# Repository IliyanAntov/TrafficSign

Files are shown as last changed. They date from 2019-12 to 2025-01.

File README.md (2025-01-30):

 <h1 align="center">Пътен знак с дистанционно управление<br/><br/>
 Adjustable traffic sign</h1>

## [Документация](./Documentation/Thesis/Diplomna_rabota_Iliyan_Antov.pdf)

## [Презентация на проекта](https://docs.google.com/presentation/d/1zqneEv3nR7Rzqj332nx1eZqfj7IUzNgIM3qGUmzLu_I/edit?usp=sharing)
<p align="center" float="left">
  
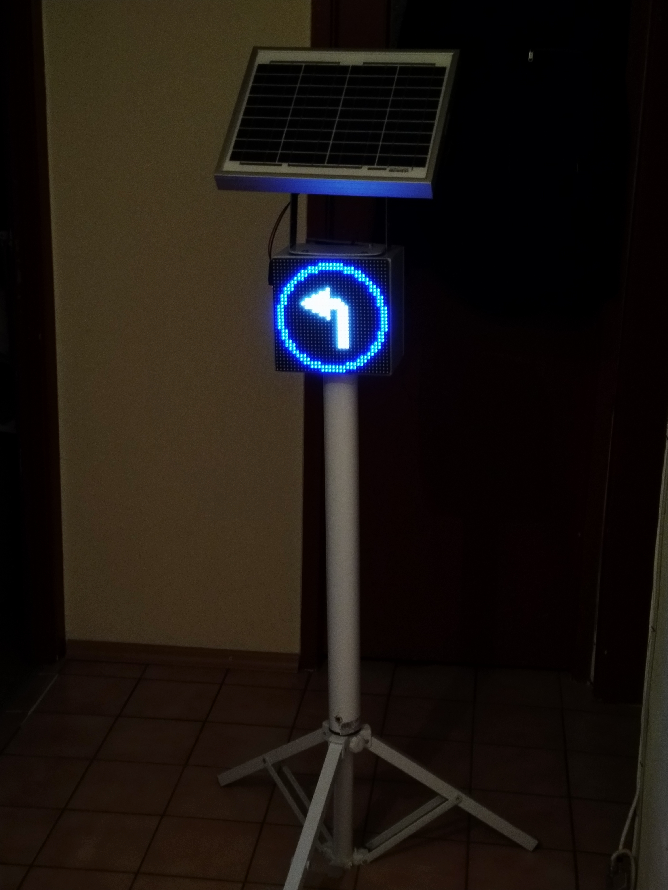
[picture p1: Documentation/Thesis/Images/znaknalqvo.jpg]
  
</p>

*Пътната обстановка се променя постоянно, но знаците, с които обозначаваме правилата, си остават едни и същи. Дипломният проект цели да разреши този проблем - пътният знак с дистанционно управление използва светодиодна матрица, на която могат да се изобразяват произволни предписания според нуждата. Той е свързан към централен сървър с помощта на GPRS връзка, което позволява дистанционното му управление чрез специално разработен управляващ софтуер.*

## Използвани технологии:
* PC application: Python + PyQt5
* Firmware: C/C++ (Arduino)
* MCU platform: AtMega328p + SIM800L
* Schematics/Layout: Altium

## Още снимки:
<p align="center" float="left">
  
  
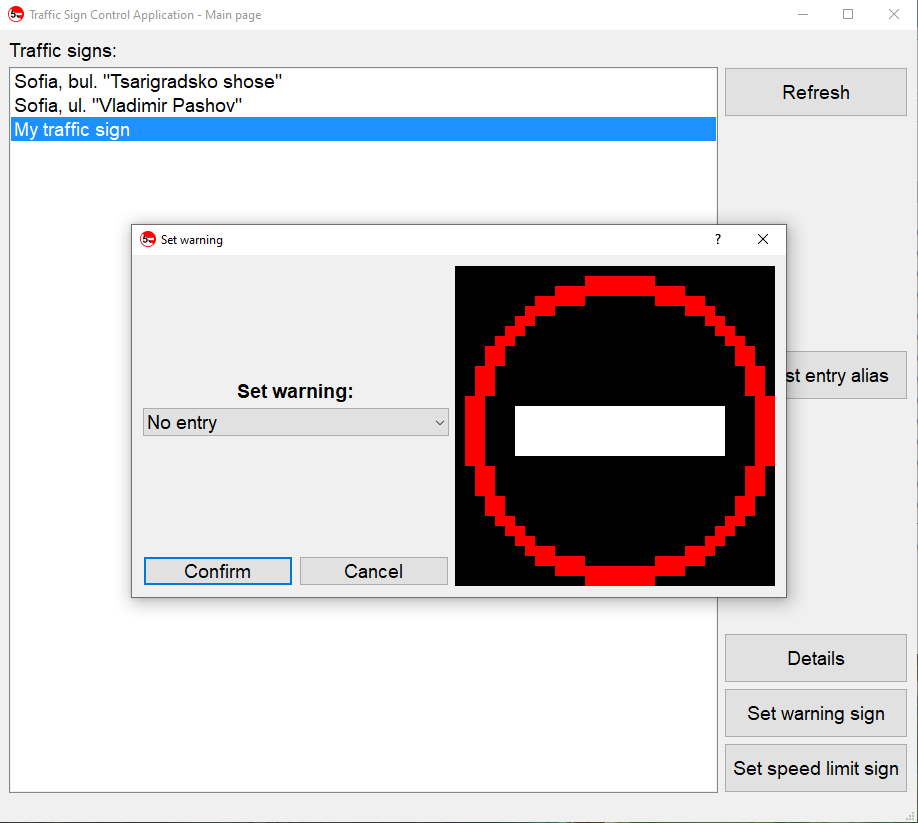
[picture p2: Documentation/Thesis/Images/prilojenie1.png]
  
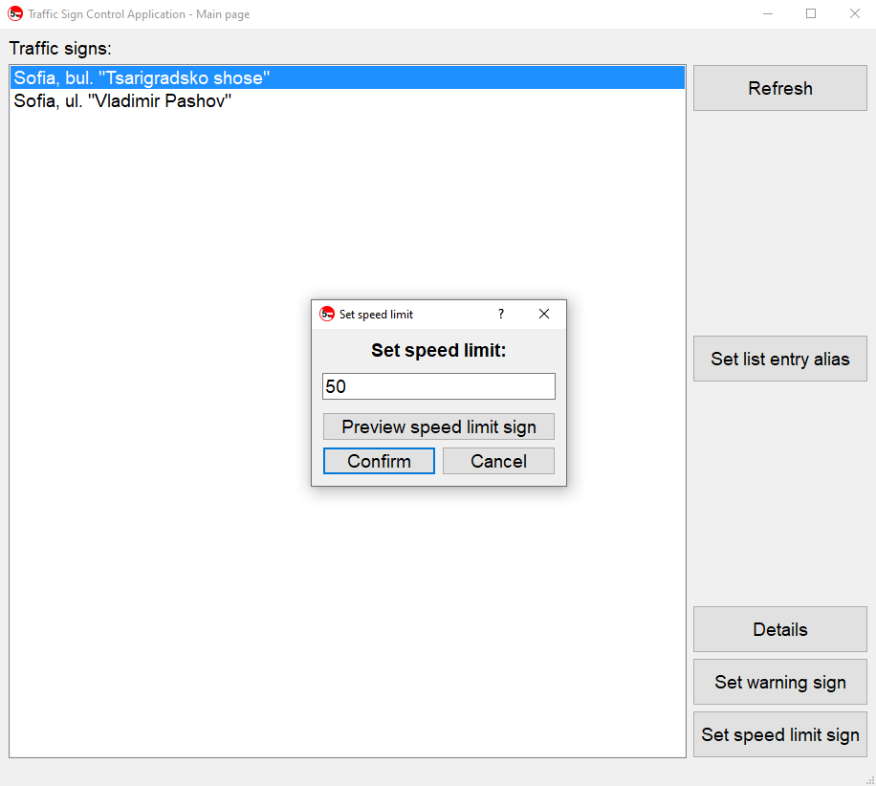
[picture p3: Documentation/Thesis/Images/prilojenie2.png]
  
</p>

## Автор:
Илиян Антов - [Iliyan Antov](https://github.com/IliyanAntov) - [i.antov2@gmail.com](i.antov2@gmail.com)

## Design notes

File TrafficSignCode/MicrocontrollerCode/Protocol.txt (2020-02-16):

Admin app -> Server

"GET ":
    1)  "devices"
        {response}: 
            [message 0]: <Number of available devices>
            [message 1-n]: <Device IMEI>
    2)  "details <IMEI>"
        {response}:
            [message 0]: <Device details string>

"SET <IMEI> ":
    1)  "speed <speed limit>" 
        {response}:
            [message 0]: <Confirmation message>
    2)  "warning <warning sign>"
        {response}:
            [message 0]: <Confirmation message>

Server -> uC

"GET ":
    1)  "dtl" = device details
        {response}:
            [message 0]: <Device details string>

"SET ":
    1)  "spd <speed limit>"
        {response}:
            [message 0]: <Confirmation message>

    2)  "wrn <warning sign code>"
            -"stp" = Stop sign
            -"gnr" = General warning (exclamation mark)
            -"tfl" = Traffic light
            -"nen" = No entry
            -"fon" = Forward only
            -"lon" = Left only
            -"ron" = Right only
        {response}:
            [message 0]: <Confirmation message>

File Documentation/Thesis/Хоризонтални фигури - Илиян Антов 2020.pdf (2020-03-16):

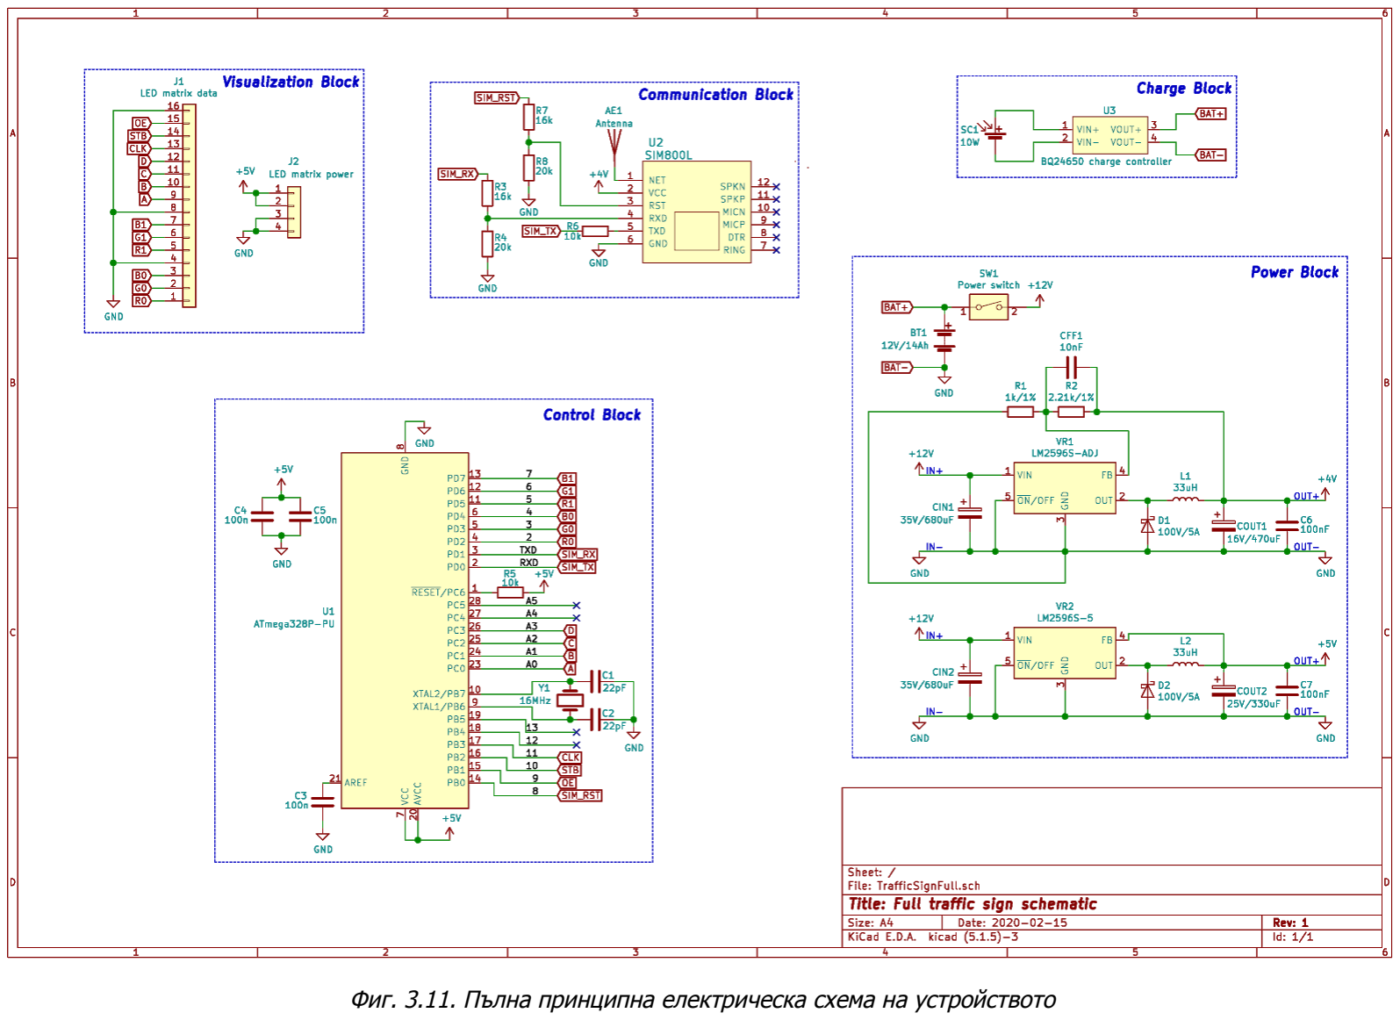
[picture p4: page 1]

Фиг. 3.11. Пълна принципна електрическа схема на устройството

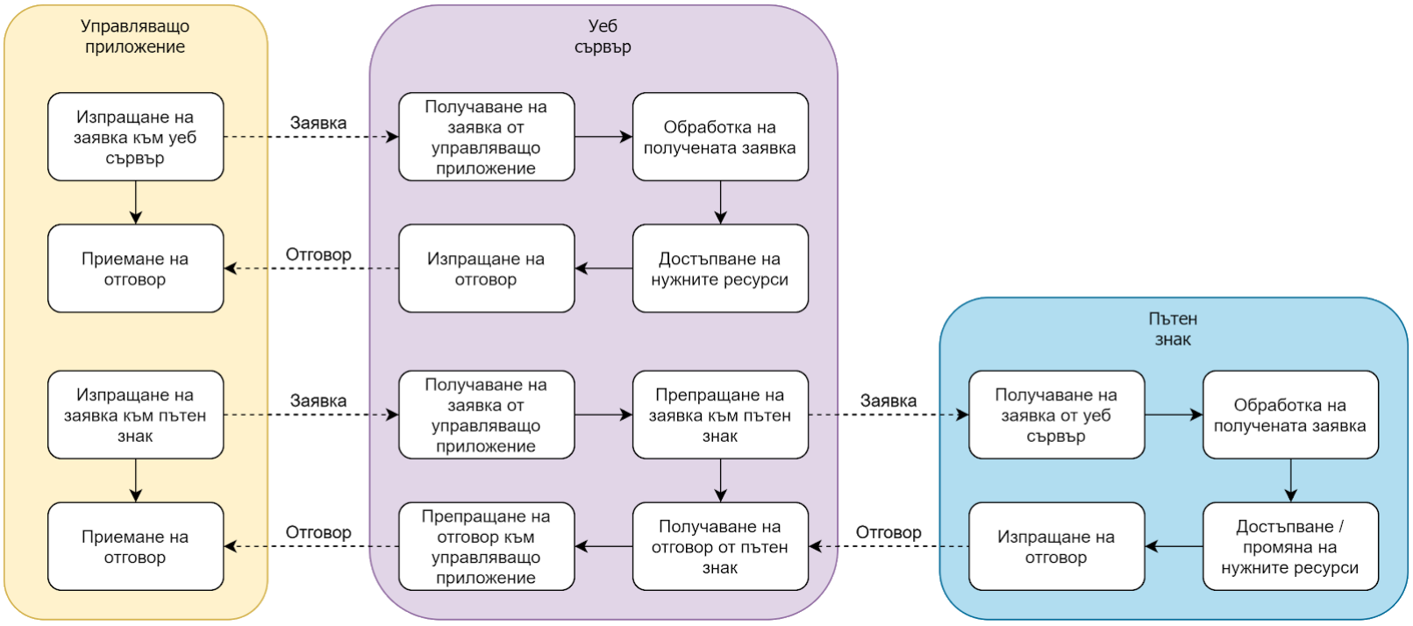
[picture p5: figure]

Фиг. 4.3. Блокова схема на алгоритъм за обмен на информация

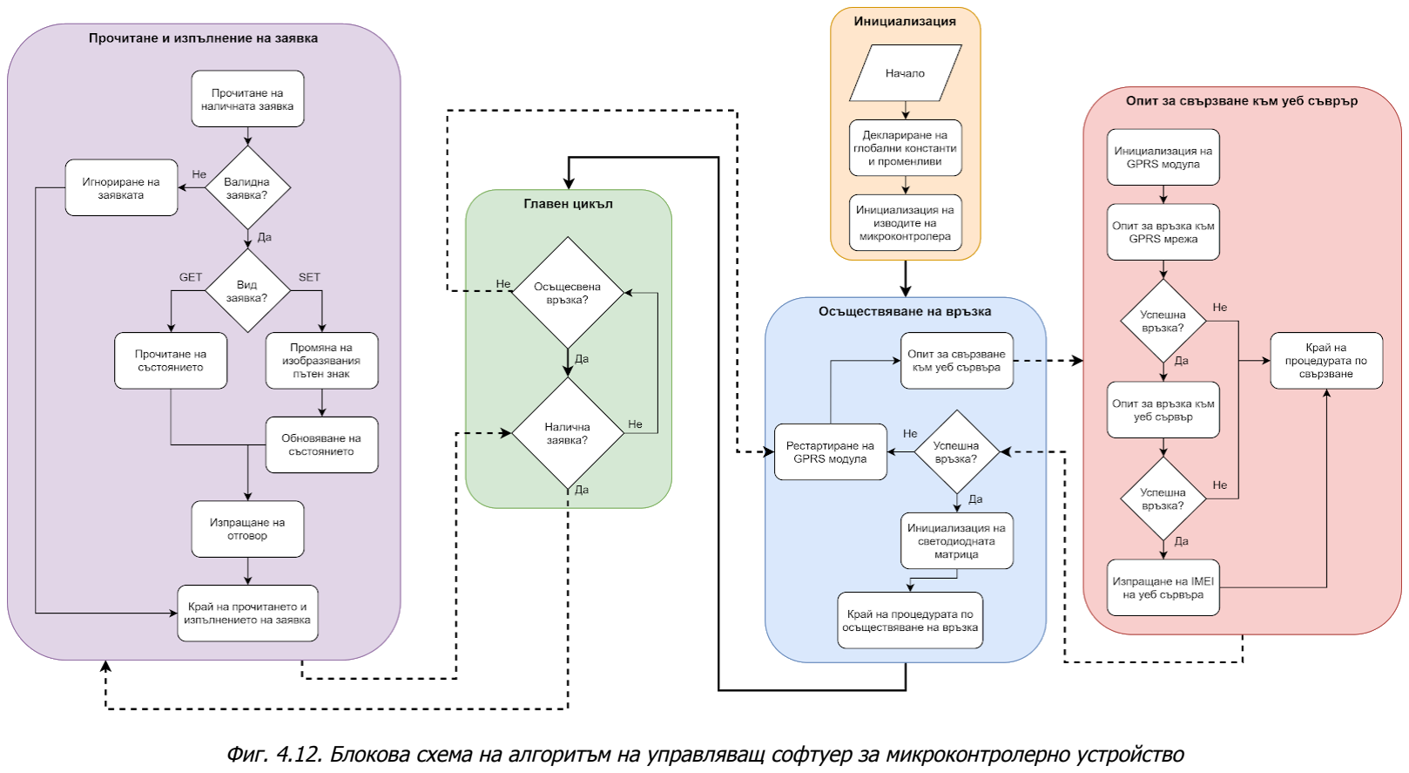
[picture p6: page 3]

Фиг. 4.12. Блокова схема на алгоритъм на управляващ софтуер за микроконтролерно устройство

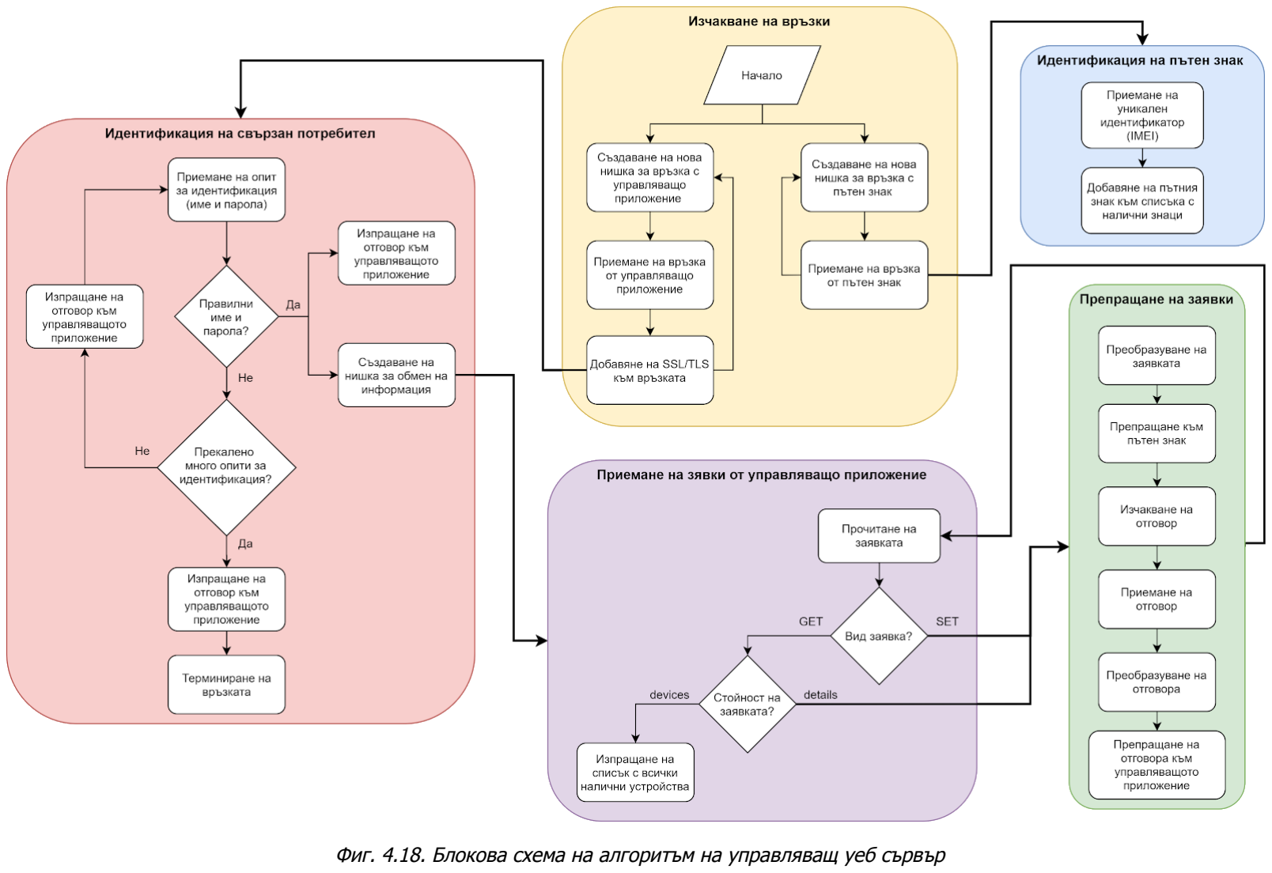
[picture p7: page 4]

Фиг. 4.18. Блокова схема на алгоритъм на управляващ уеб сървър

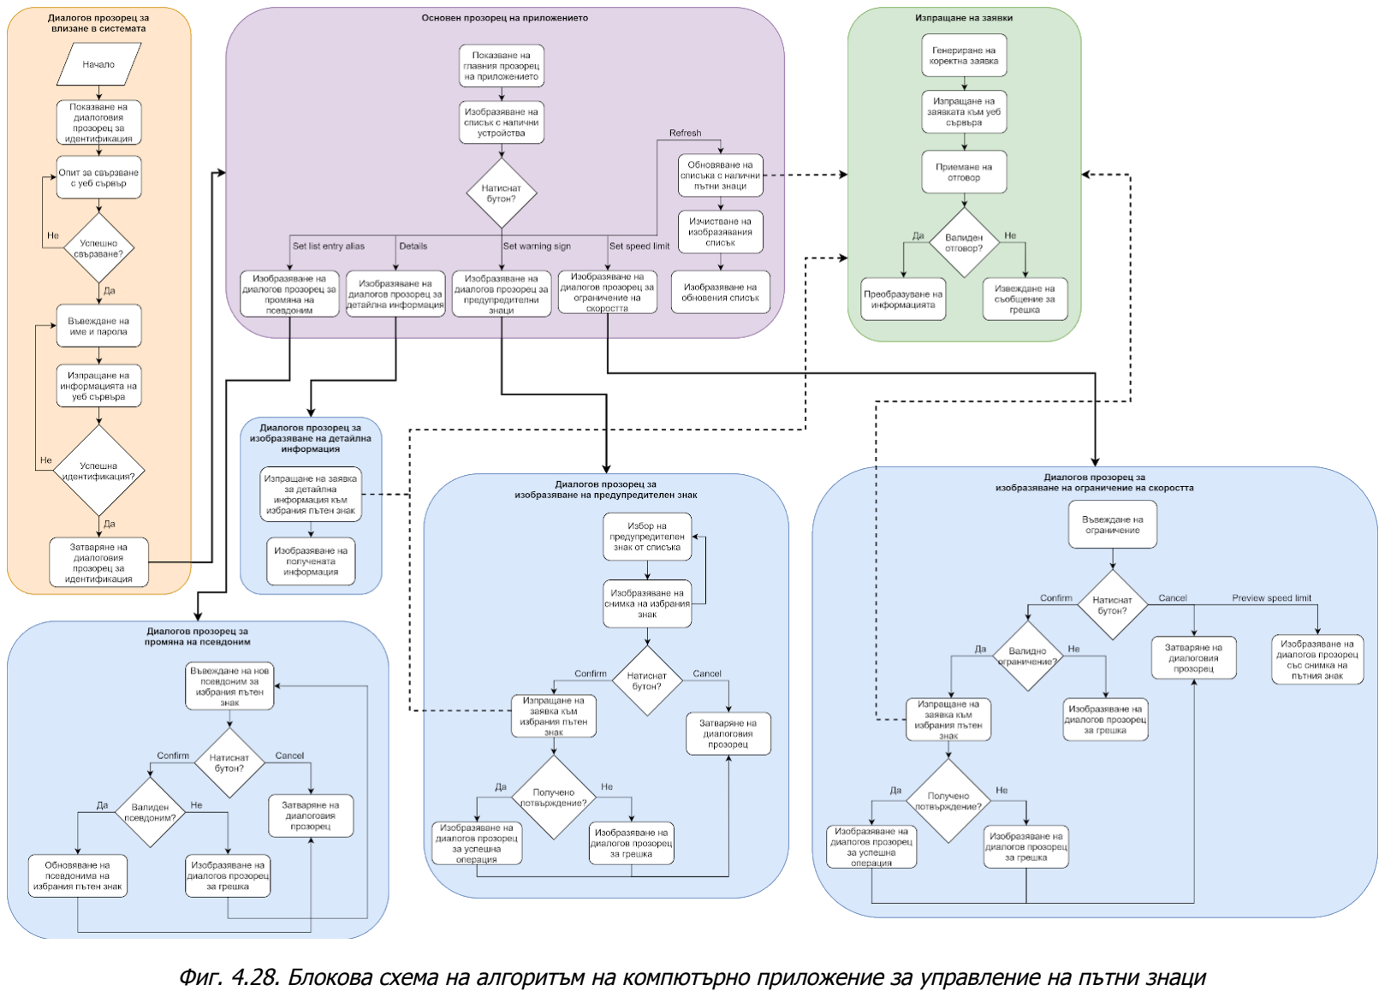
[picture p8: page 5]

Фиг. 4.28. Блокова схема на алгоритъм на компютърно приложение за управление на пътни знаци

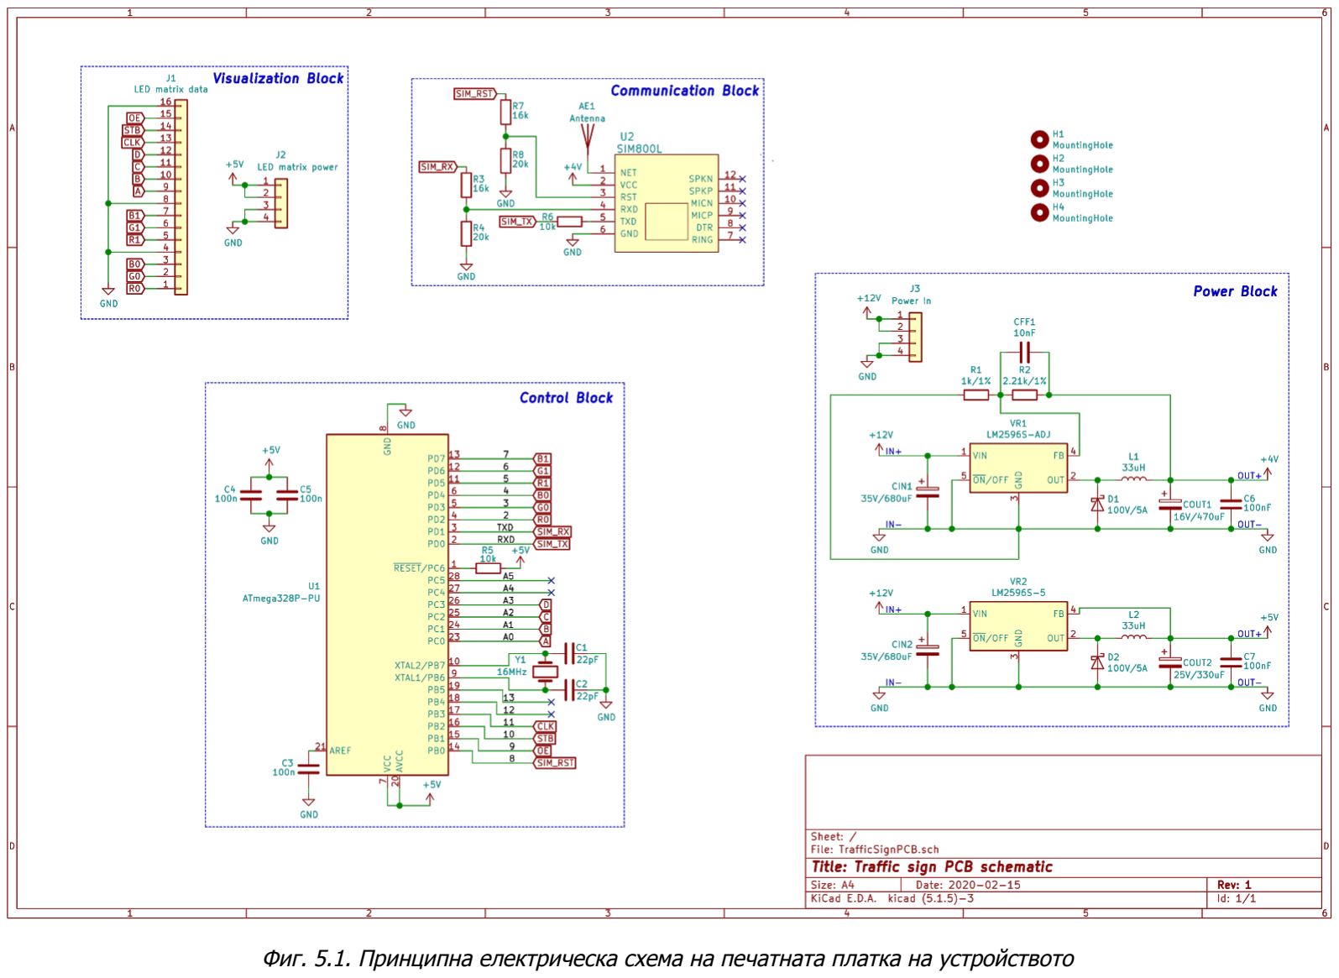
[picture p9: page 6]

Фиг. 5.1. Принципна електрическа схема на печатната платка на устройството

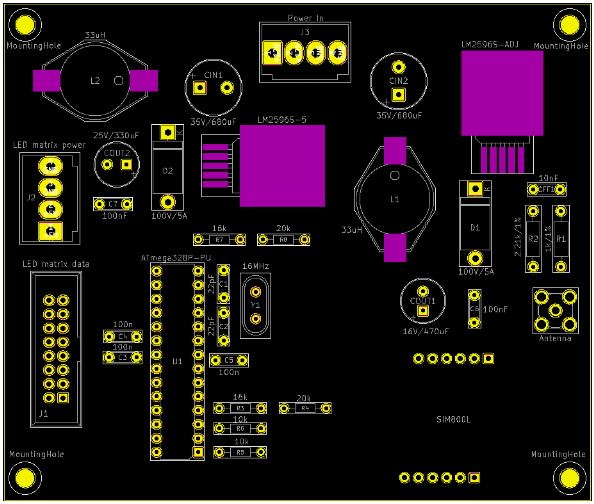
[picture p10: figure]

Фиг. 5.2. Разположение на елементите върху печатната платка

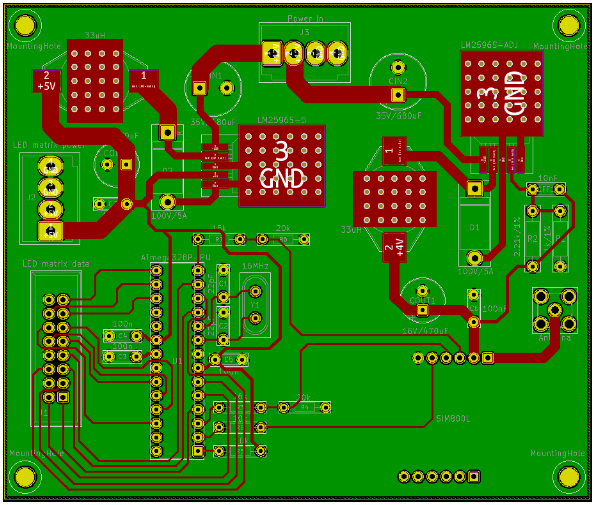
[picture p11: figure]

Фиг. 5.3. Опроводена печатна платка

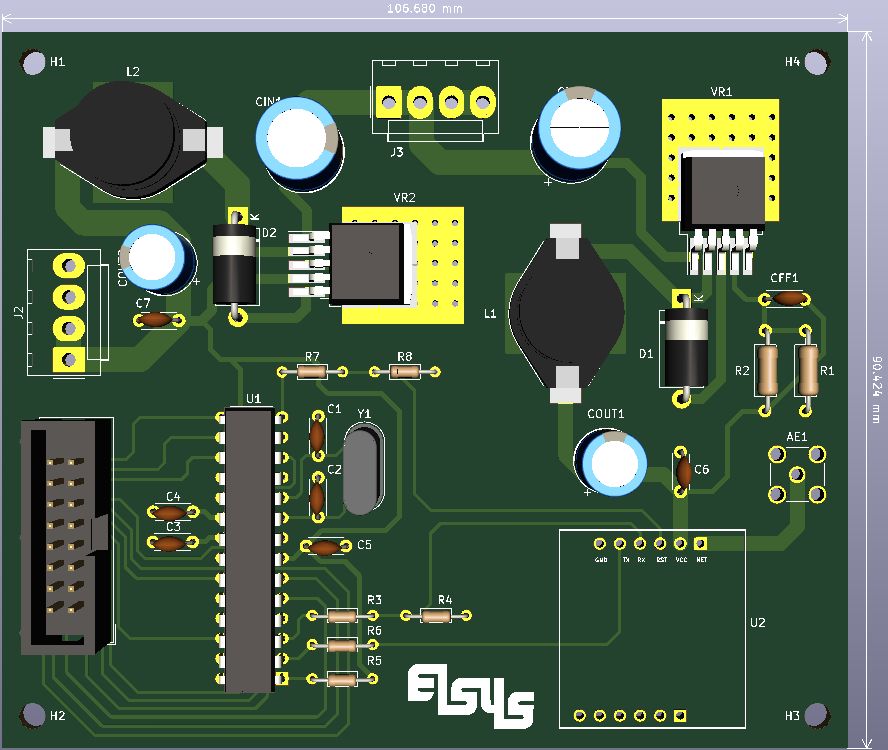
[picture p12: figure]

Фиг. 5.5. 3D изглед на печатната платка

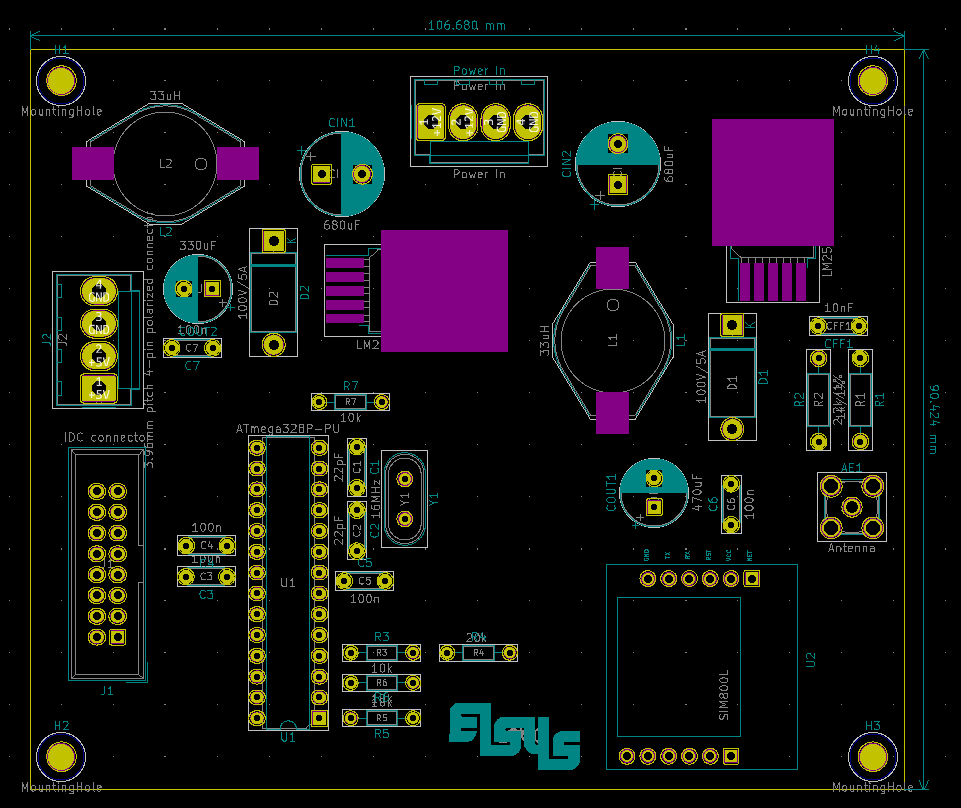
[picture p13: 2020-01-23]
TrafficSignSchematic/TrafficSignPCB/Images/TrafficSignPCBElements.png

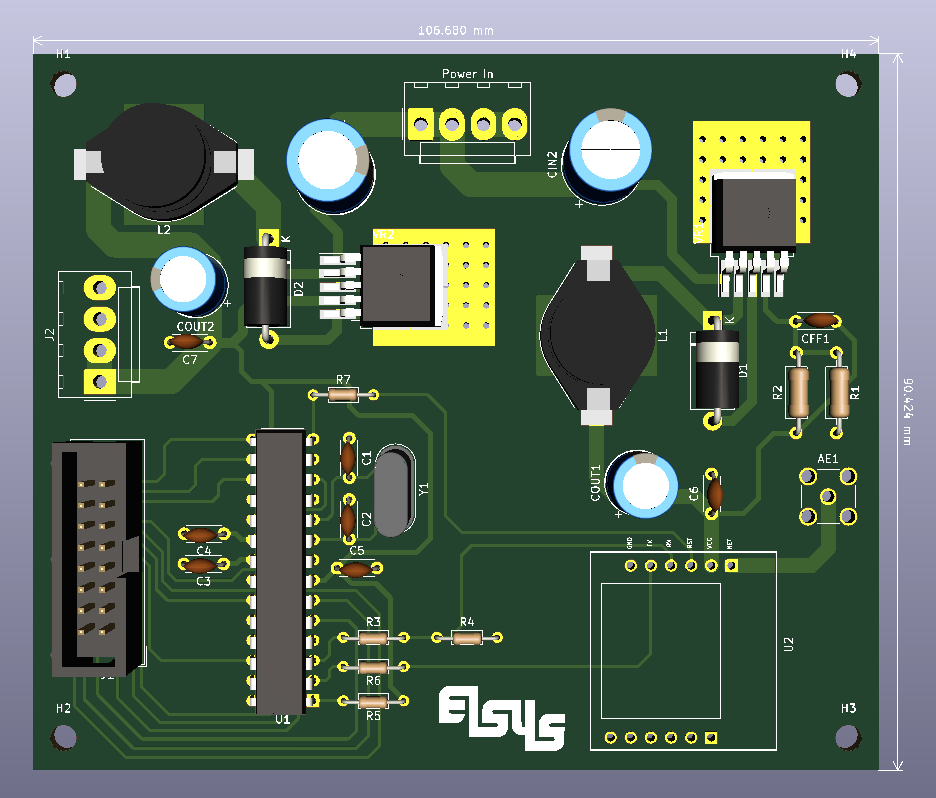
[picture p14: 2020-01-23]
TrafficSignSchematic/TrafficSignPCB/Images/TrafficSignPCB3D.png

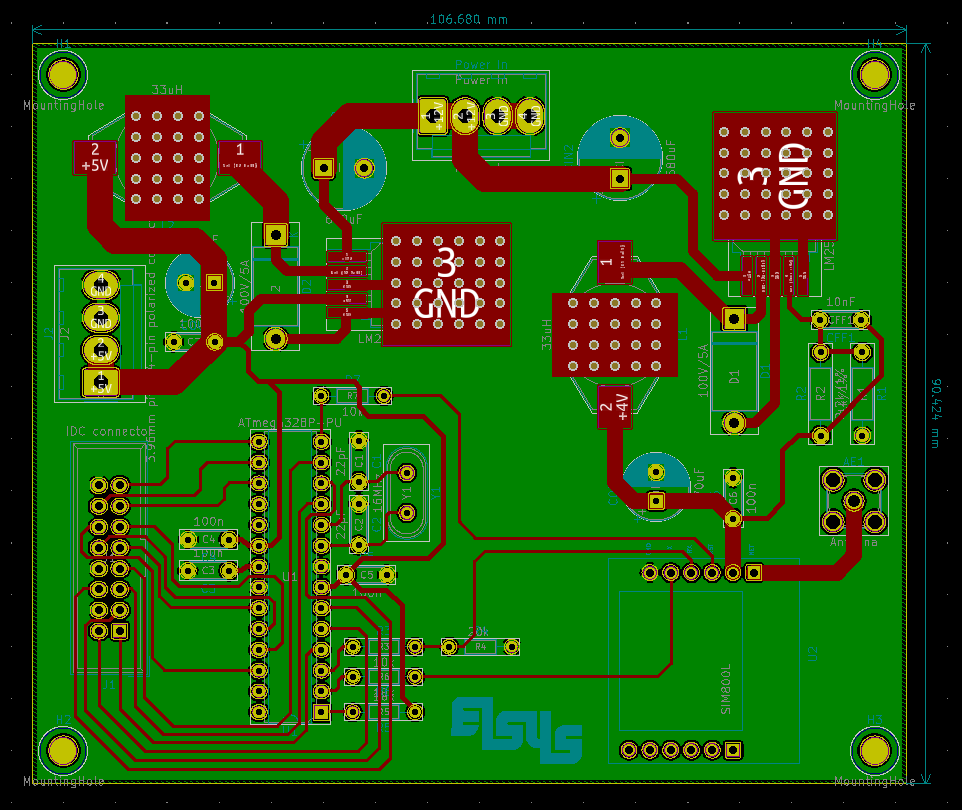
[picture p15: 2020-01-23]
TrafficSignSchematic/TrafficSignPCB/Images/TrafficSignPCBRoutingBack.png

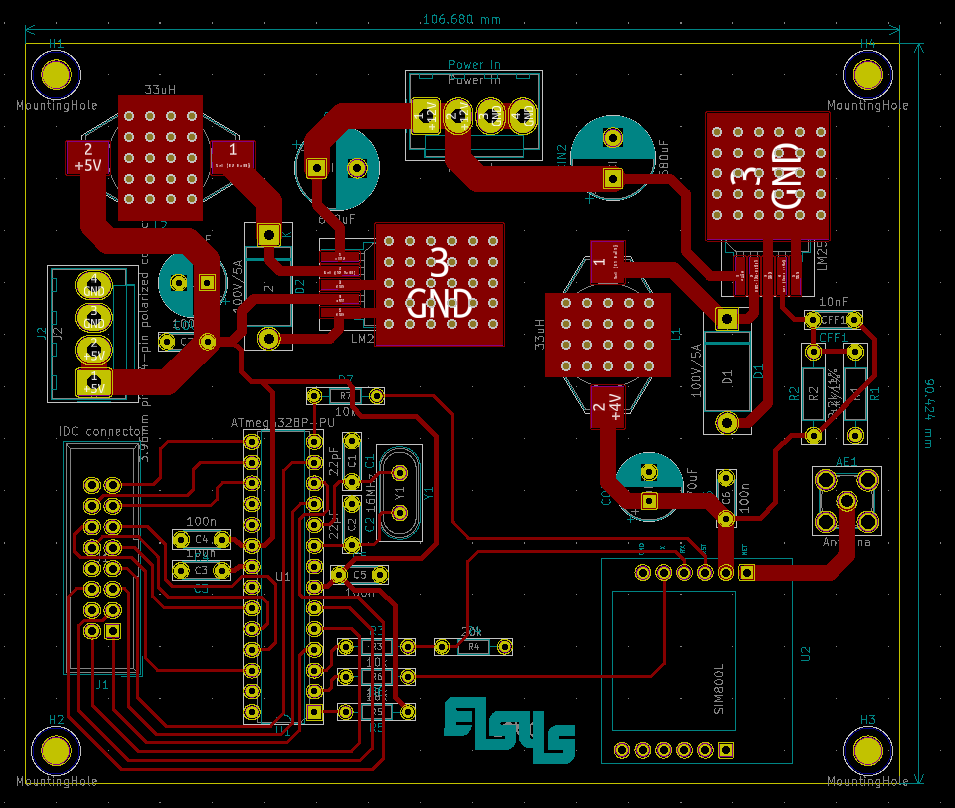
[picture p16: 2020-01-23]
TrafficSignSchematic/TrafficSignPCB/Images/TrafficSignPCBRoutingFront.png

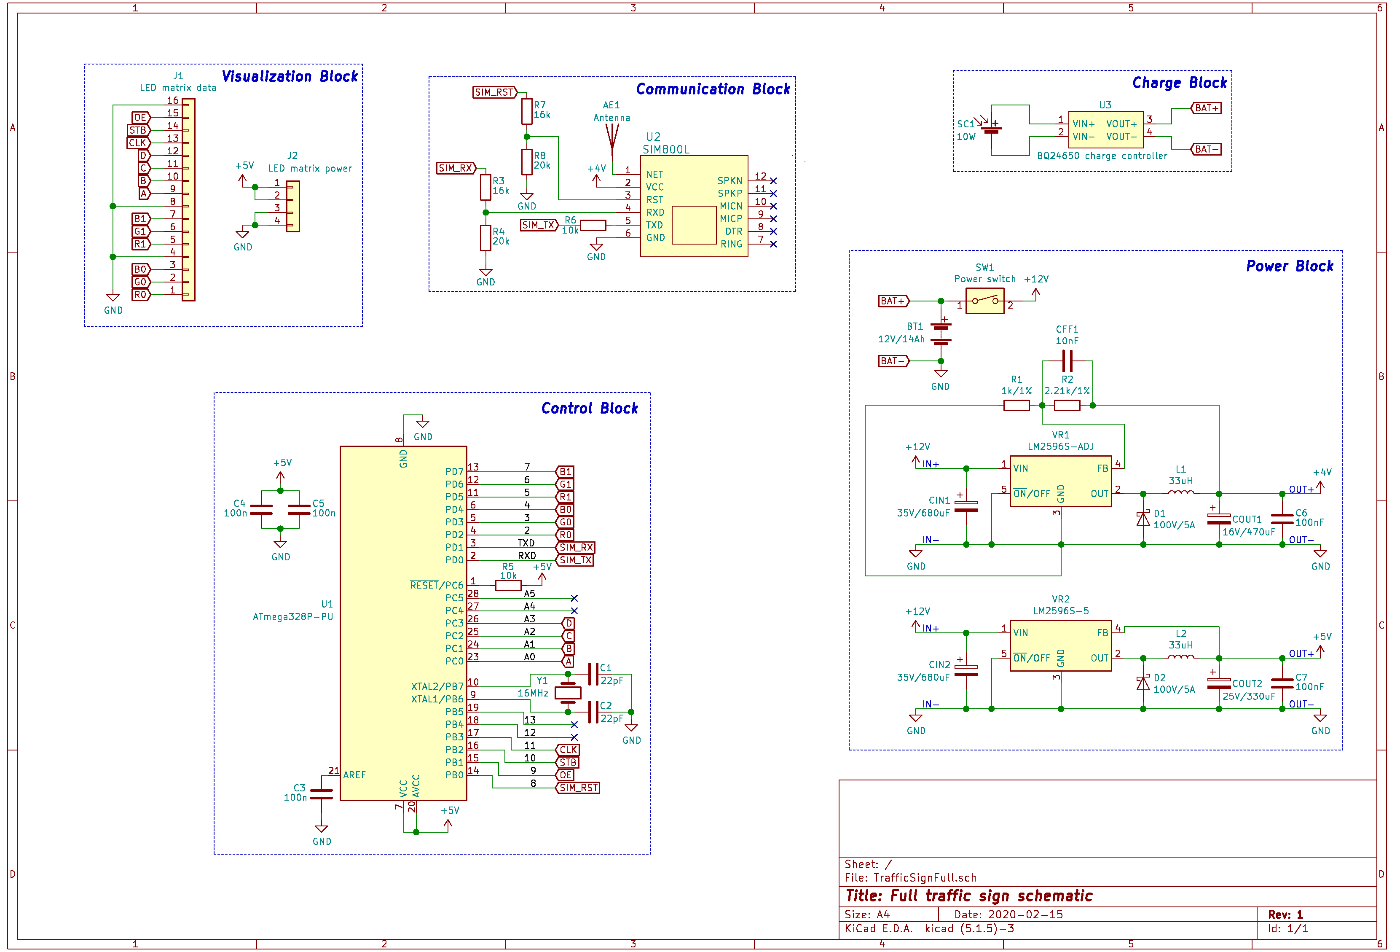
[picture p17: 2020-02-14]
TrafficSignSchematic/TrafficSignFull/Images/TrafficSignFull.png

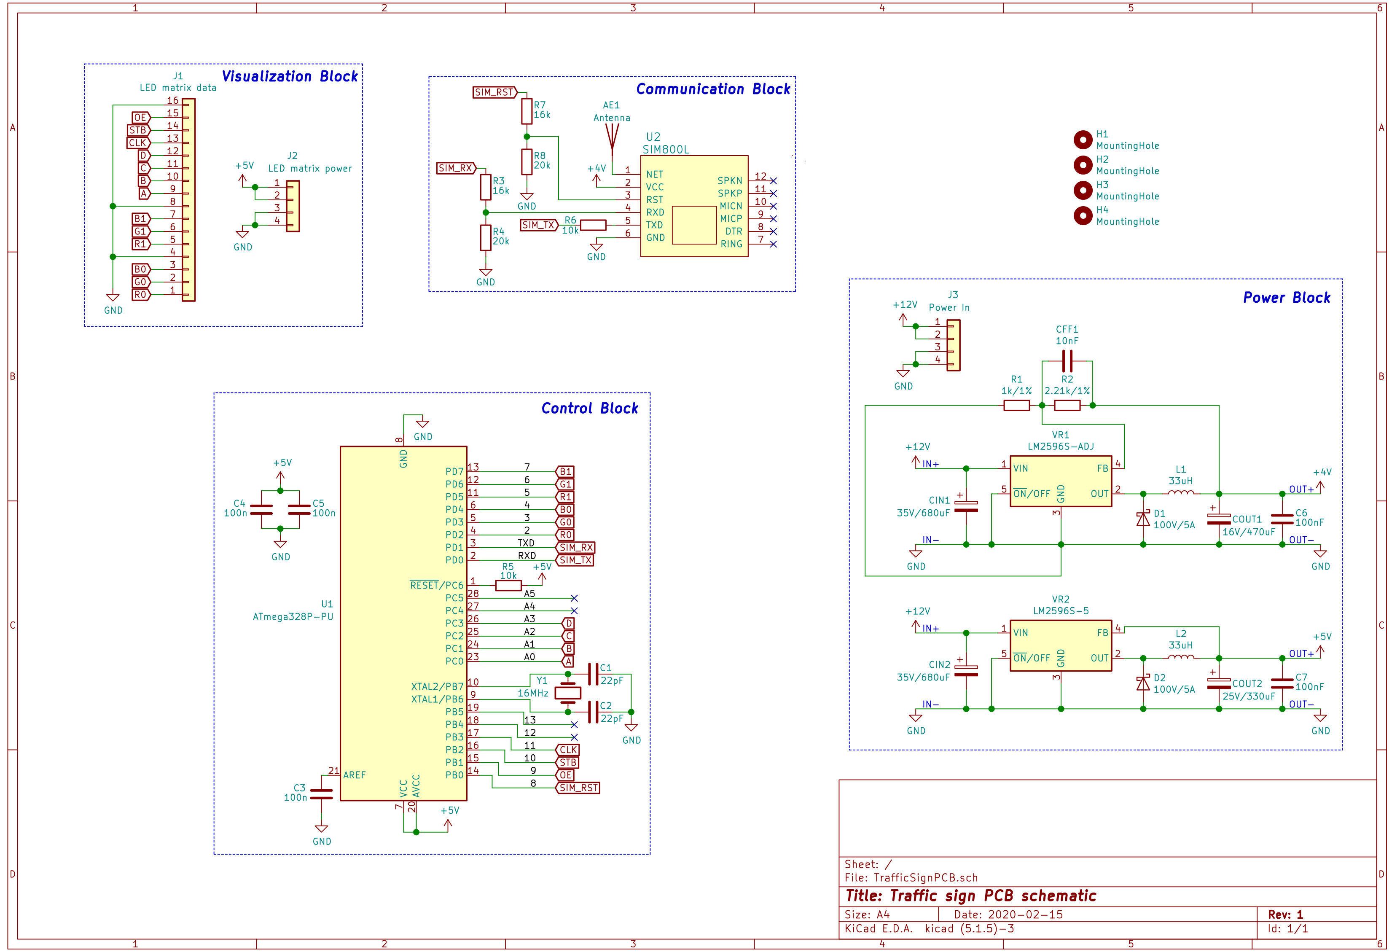
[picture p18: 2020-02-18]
TrafficSignSchematic/TrafficSignPCB/Images/TrafficSignPCB.png

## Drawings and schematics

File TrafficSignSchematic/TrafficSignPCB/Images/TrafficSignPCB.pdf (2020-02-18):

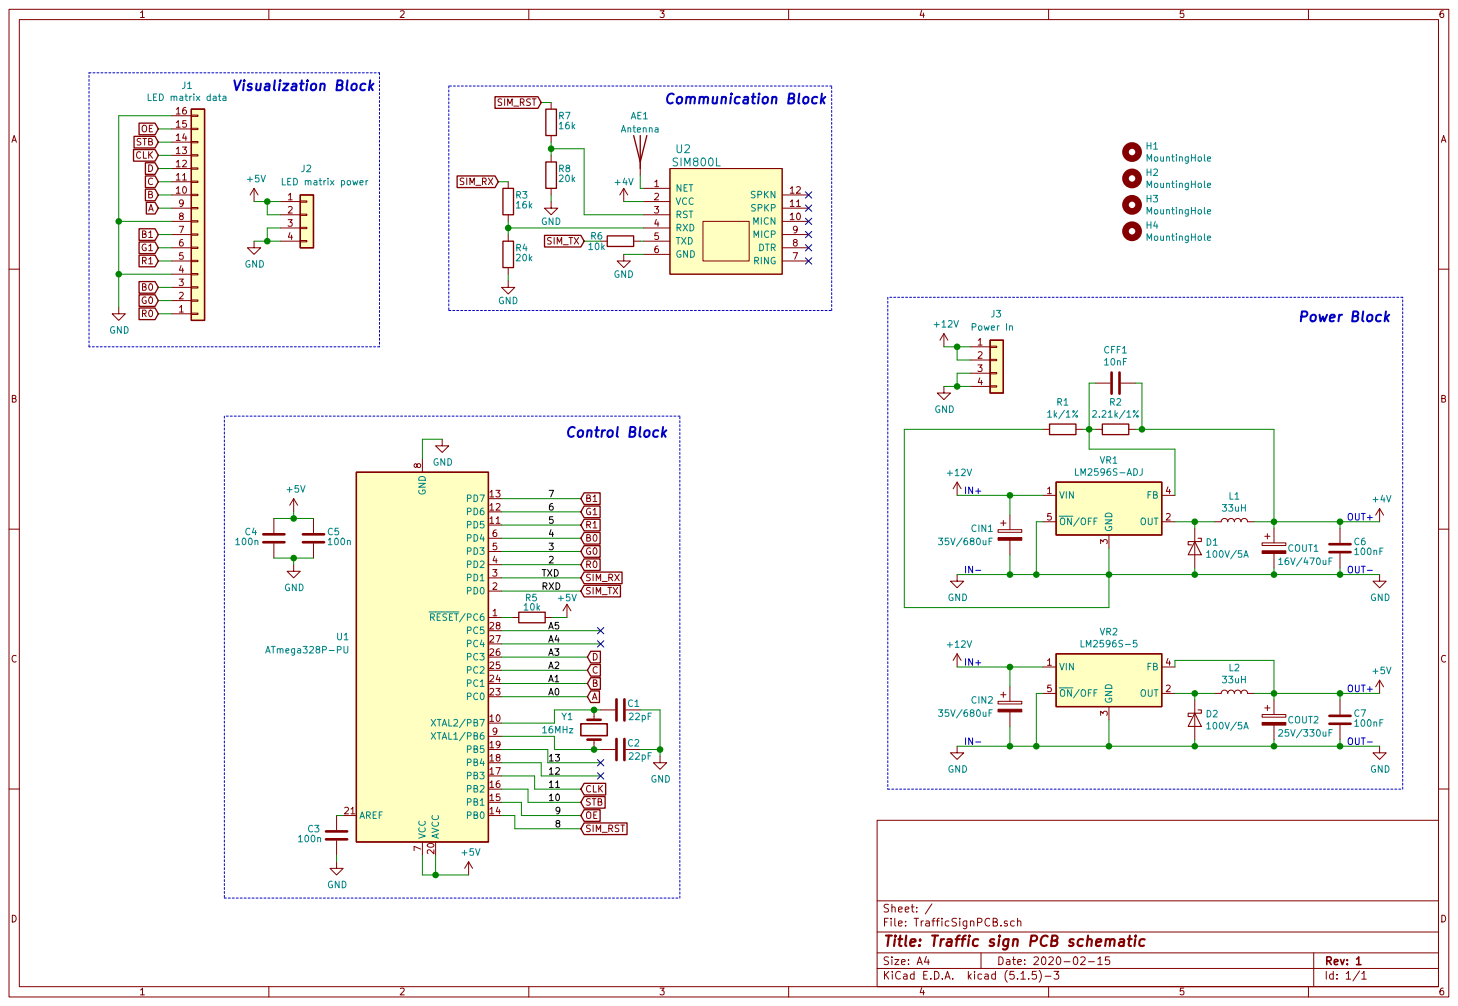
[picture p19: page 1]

OUT- OUT+ OUT+ OUT- Communication Block

J3 Power In GND GND GND

Id: 1/1 Title: Traffic sign PCB schematic

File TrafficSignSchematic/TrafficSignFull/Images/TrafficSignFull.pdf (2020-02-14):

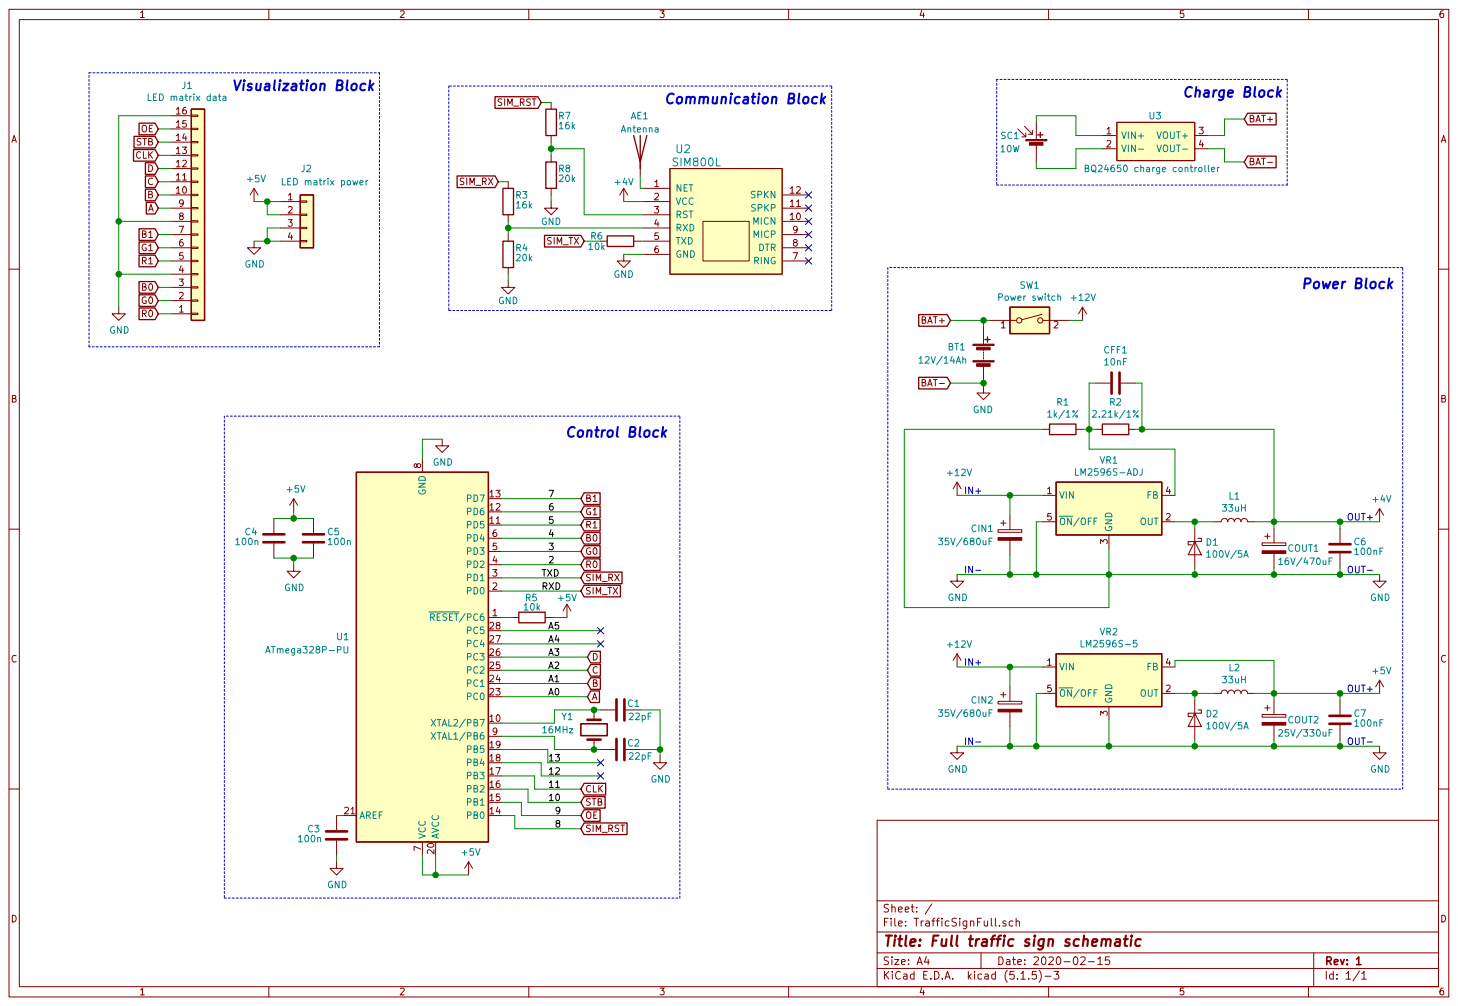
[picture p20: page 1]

File: TrafficSignFull.sch Sheet: / C3

Id: 1/1 Title: Full traffic sign schematic

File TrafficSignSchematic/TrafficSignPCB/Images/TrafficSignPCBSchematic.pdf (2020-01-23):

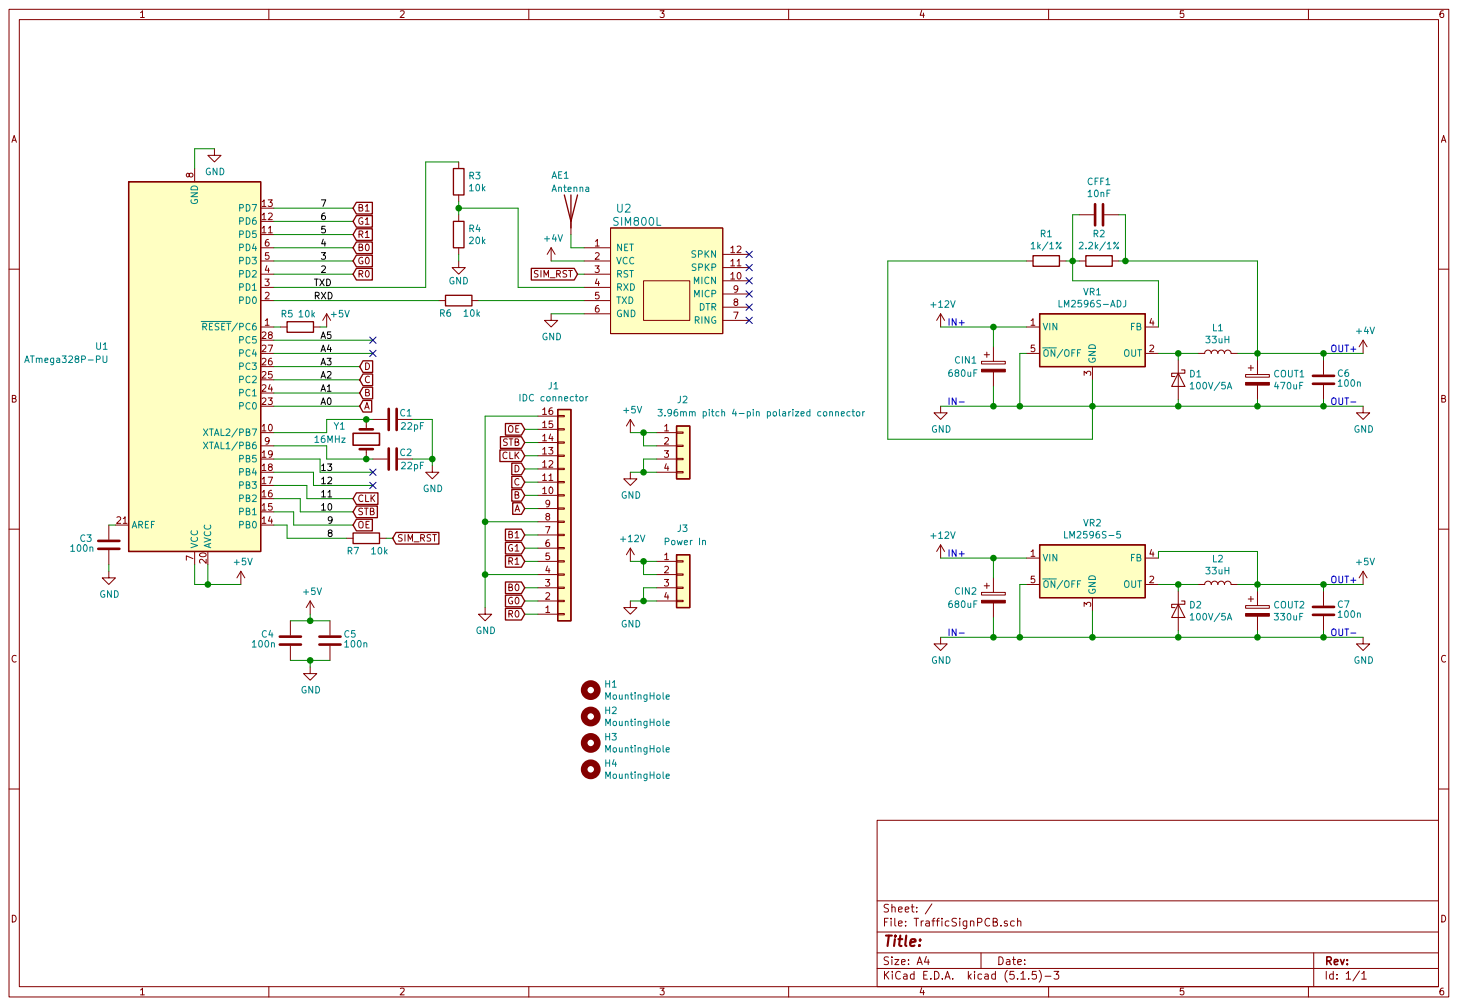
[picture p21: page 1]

File: TrafficSignPCB.sch Sheet: / GND

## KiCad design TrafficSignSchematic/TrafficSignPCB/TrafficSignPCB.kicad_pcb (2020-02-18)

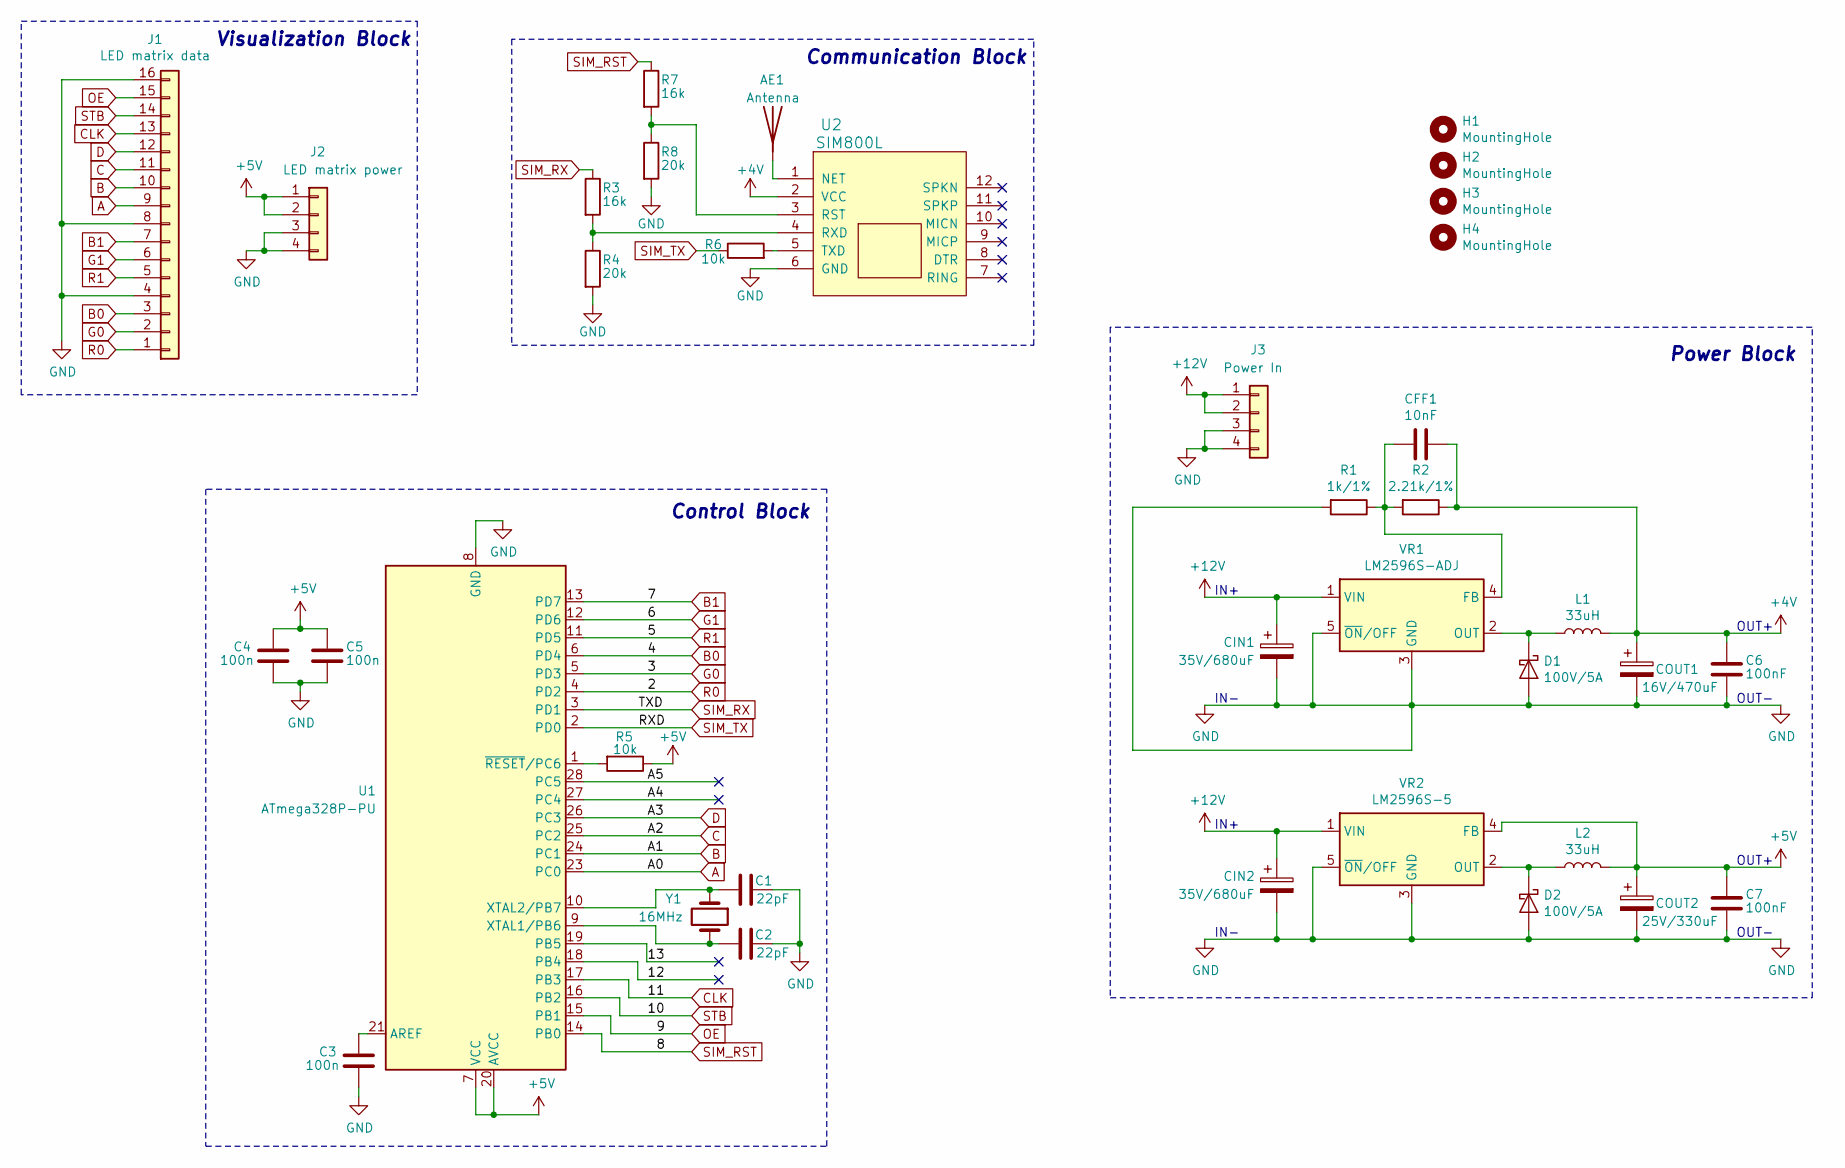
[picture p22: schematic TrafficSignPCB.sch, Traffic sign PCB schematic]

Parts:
AE1: Antenna; SMA_Amphenol_901-144_Vertical
C1, C2: 22pF; C_Disc_D4.3mm_W1.9mm_P5.00mm
C3, C4, C5: 100n; C_Disc_D4.3mm_W1.9mm_P5.00mm
C6, C7: 100nF; C_Disc_D4.3mm_W1.9mm_P5.00mm
CFF1: 10nF; C_Disc_D4.3mm_W1.9mm_P5.00mm
CIN1, CIN2: 35V/680uF; CP_Radial_D10.0mm_P5.00mm
COUT1: 16V/470uF; CP_Radial_D8.0mm_P3.50mm
COUT2: 25V/330uF; CP_Radial_D8.0mm_P3.50mm
D1, D2: 100V/5A; D_DO-27_P12.70mm_Horizontal
H1, H2, H3, H4: MountingHole; MountingHole_3.2mm_M3_ISO14580
J1: LED matrix data; IDC-Header_2x08_P2.54mm_Vertical
J2: LED matrix power; Molex_KK-396_A-41791-0004_1x04_P3.96mm_Vertical
J3: Power In; Molex_KK-396_A-41791-0004_1x04_P3.96mm_Vertical
L1, L2: 33uH; L_Bourns_SDR1806
R1: 1k/1%; R_Axial_DIN0207_L6.3mm_D2.5mm_P10.16mm_Horizontal
R2: 2.21k/1%; R_Axial_DIN0207_L6.3mm_D2.5mm_P10.16mm_Horizontal
R3, R7: 16k; R_Axial_DIN0204_L3.6mm_D1.6mm_P7.62mm_Horizontal
R4, R8: 20k; R_Axial_DIN0204_L3.6mm_D1.6mm_P7.62mm_Horizontal
R5, R6: 10k; R_Axial_DIN0204_L3.6mm_D1.6mm_P7.62mm_Horizontal
U1: ATmega328P-PU; DIP-28_W7.62mm
U2: SIM800L; Sim800L
VR1: LM2596S-ADJ; TO-263-5_TabPin3
VR2: LM2596S-5; TO-263-5_TabPin3
Y1: 16MHz; Crystal_HC49-U_Vertical

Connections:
+4V: C6.1, CFF1.1, COUT1.1, L1.2, R2.1, U2.2 (VCC)
+5V: C4.1, C5.1, C7.1, COUT2.1, J2.1, J2.2, L2.2, R5.1, U1.7 (VCC), U1.20 (AVCC), VR2.4 (FB)
+12V: CIN1.1, CIN2.1, J3.1, J3.2, VR1.1 (VIN), VR2.1 (VIN)
/12: U1.18 (PB4)
/13: U1.19 (PB5)
/A4: U1.27 (PC4)
/A5: U1.28 (PC5)
A: J1.9, U1.23 (PC0)
B: J1.10, U1.24 (PC1)
B0: J1.3, U1.6 (PD4)
B1: J1.7, U1.13 (PD7)
C: J1.11, U1.25 (PC2)
CLK: J1.13, U1.17 (PB3)
D: J1.12, U1.26 (PC3)
G0: J1.2, U1.5 (PD3)
G1: J1.6, U1.12 (PD6)
GND: C1.1, C2.1, C3.2, C4.2, C5.2, C6.2, C7.2, CIN1.2, CIN2.2, COUT1.2, COUT2.2, D1.2 (A), D2.2 (A), J1.4, J1.8, J1.16, J2.3, J2.4, J3.3, J3.4, R1.2, R4.2, R8.2, U1.8 (GND), U1.22 (GND), U2.6 (GND), VR1.3 (GND), VR1.5 (~ON~/OFF), VR2.3 (GND), VR2.5 (~ON~/OFF)
unnamed: AE1.1, U2.1 (NET)
unnamed: C1.2, U1.10 (XTAL2/PB7), Y1.1
unnamed: C2.2, U1.9 (XTAL1/PB6), Y1.2
unnamed: C3.1, U1.21 (AREF)
unnamed: CFF1.2, R1.1, R2.2, VR1.4 (FB)
unnamed: D1.1 (K), L1.1, VR1.2 (OUT)
unnamed: D2.1 (K), L2.1, VR2.2 (OUT)
unnamed: R3.2, R4.1, U2.4 (RXD)
unnamed: R5.2, U1.1 (~RESET~/PC6)
unnamed: R6.2, U2.5 (TXD)
unnamed: R7.2, R8.1, U2.3 (RST)
OE: J1.15, U1.15 (PB1)
R0: J1.1, U1.4 (PD2)
R1: J1.5, U1.11 (PD5)
SIM_RST: R7.1, U1.14 (PB0)
SIM_RX: R3.1, U1.3 (PD1)
SIM_TX: R6.1, U1.2 (PD0)
STB: J1.14, U1.16 (PB2)

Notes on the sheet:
IN-
IN+
OUT-
OUT+
Visualization Block
Communication Block
Control Block
Power Block

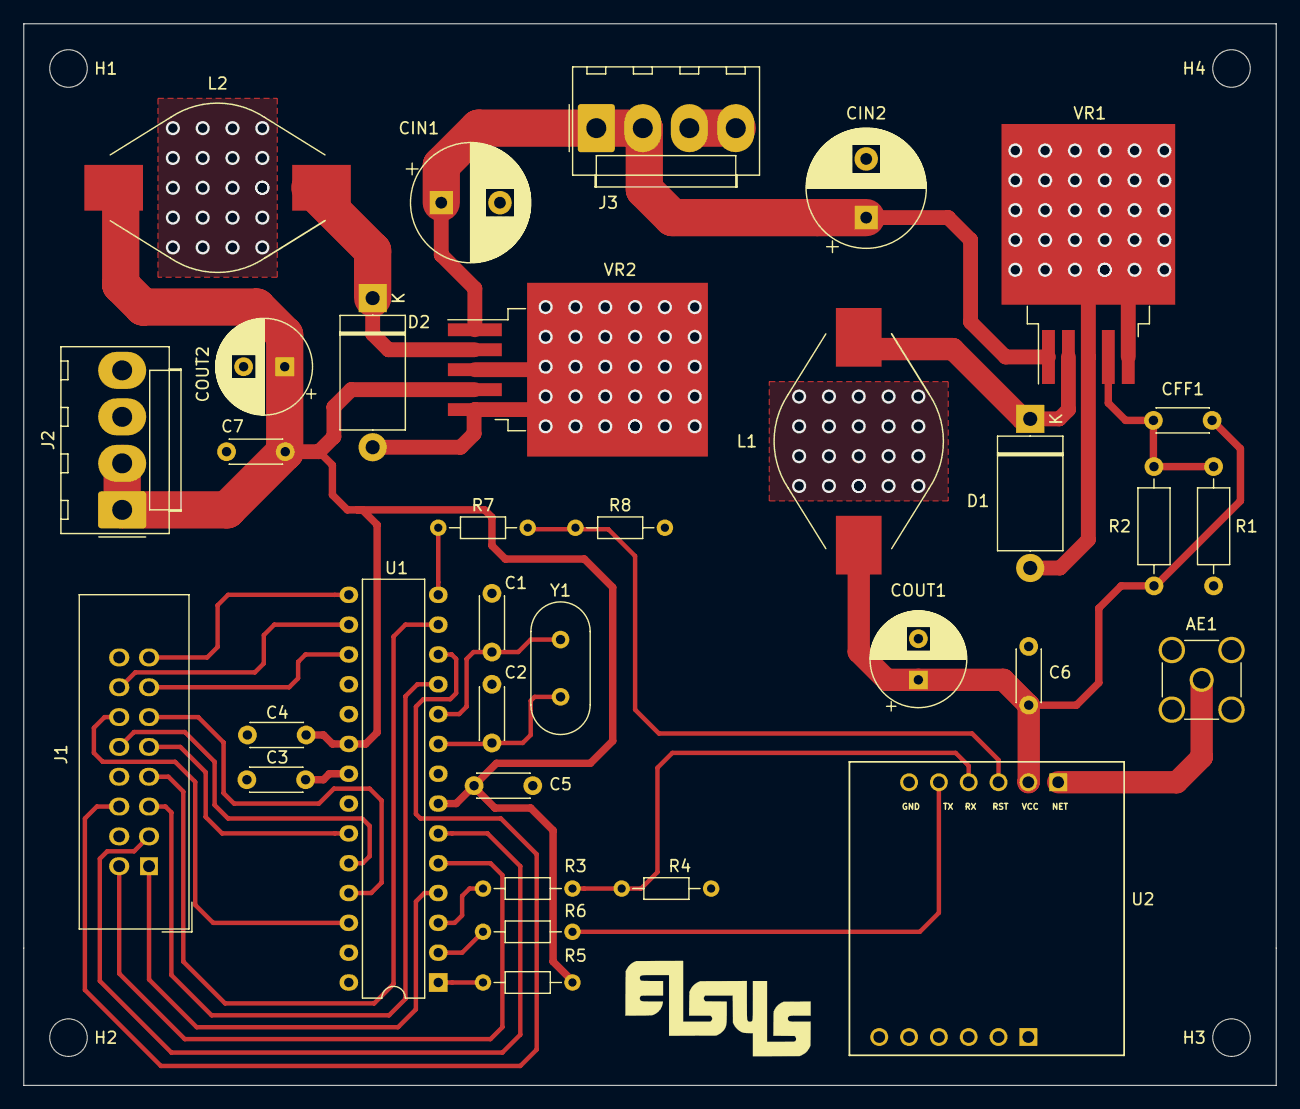
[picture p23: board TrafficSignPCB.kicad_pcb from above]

Board: 2 copper layers, 106.7 x 90.4 mm, 37 parts (0 on the bottom side), 31 nets.

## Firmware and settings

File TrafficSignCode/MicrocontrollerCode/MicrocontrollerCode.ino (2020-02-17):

// The GPRS module model
// (Required by the TinyGsmClient.h library)
#define TINY_GSM_MODEM_SIM800

#include <RGBmatrixPanel.h>
#include <TinyGsmClient.h>

// The interface on which AT commands will be sent
#define SerialAT Serial

// LED matrix pins
#define CLK 11
#define OE 9
#define LAT 10
#define A A0
#define B A1
#define C A2
#define D A3

// The APN of the ISP's GPRS network
const char apn[] = "internet.vivacom.com";
// The username of the ISP's GPRS network
const char gprsUser[] = "VIVACOM";
// The password of the ISP's GPRS network
const char gprsPass[] = "VIVACOM";

// Server details
// Static public IPv4 address of the web server
const char server[] = "3.125.80.10";
// Connection port
const int port = 19119;

char command[4];  // Last received command
char request[4];  // Last received request
char value[4];    // Last received value
int index = 0;    // Index (Used for loops)
char current;     // Current char (Used for reading from the serial port)

char currentState[8] = {"unk unk"};  // Current device state (Default)

// LED matrix object (RGBmatrixPanel.h library)
RGBmatrixPanel matrix(A, B, C, D, CLK, LAT, OE, false);
// GPRS modem object (TinyGsmClient.h library)
TinyGsm modem(SerialAT);
// GPRS connection client object (TinyGsmClient.h library)
TinyGsmClient client(modem);

// Performs initial device setup
void setup() {
  // Initialize the serial communication
  InitModulePins();

  // Initialize the GPRS module and connect to the web server
  bool state = RunConnectionProcedure();
  // Until a connection is established:
  while (!state) {
    // Restart the GPRS module
    RestartModule();
    // Retry the connection
    state = RunConnectionProcedure();
  }
  // Initialize the LED matrix panel
  InitMatrix();
}

// Main program loop
// (keeps running until the device is turned off)
void loop() {
  // While the GPRS module is connected to the web server:
  while (client.connected()) {
    // If information is available to receive:
    if (client.available()) {
      // Read and handle incoming request
      ReadRequest();
    }
  }
  // If the GPRS module disconnects from the server:
  // Restart the module
  RestartModule();
  // Attempt another connection to the web server
  RunConnectionProcedure();
}

// Initializes the GPRS module's pins
void InitModulePins() {
  pinMode(8, OUTPUT);  // RST pin
  // Set the default RST pin state - HIGH (normal operation)
  digitalWrite(8, HIGH);
  // Begin the serial communication at 9600 baud rate
  SerialAT.begin(9600);
  // Wait 1000ms
  delay(1000);
}

// Defines the server connection procedure
bool RunConnectionProcedure() {
  // Initialize the GPRS modem
  InitModem();

  // Connect to the ISP's GPRS network
  bool state = ConnectToAPN();
  // If the connection was unsuccessful - abort the procedure
  if (!state) {
    return false;
  }

  // Connect to the web server
  state = ConnectToServer();
  // If the connection was unsuccessful - abort the procedure
  if (!state) {
    return false;
  }

  // Send the device's IMEI to the web server
  SendIMEI();
  // Procedure successful
  return true;
}

// Initializes the GPRS module
void InitModem() {
  // Initialize the modem
  modem.init();
}

// Attempts to establish a connection to the ISP's GPRS network
bool ConnectToAPN() {
  // Connect the modem to the GPRS network
  modem.gprsConnect(apn, gprsUser, gprsPass);
  // If the network doesn't respond within 24s:
  if (!modem.waitForNetwork(240000L)) {
    return false;
  }
  return true;
}

// Attempts to establish a connection to the web server
bool ConnectToServer() {
  // Try connecting to the web server
  // If the connection is unsuccessful:
  if (!client.connect(server, port)) {
    return false;
  }
  // Wait 2000ms
  delay(2000);
  return true;
}

// Sends the device's IMEI to the web server
void SendIMEI() {
  // Retrieve and store the IMEI
  String IMEI = modem.getIMEI();
  // Send the IMEI to the server in the correct format
  client.print("IMEI: " + IMEI);
}

// Hard resets the GPRS module via the RST pin
void RestartModule() {
  // Pull the RST pin low (Reset the module)
  digitalWrite(8, LOW);
  // Wait 500ms
  delay(500);
  // Pull the RST pin high (Enable normal operation)
  digitalWrite(8, HIGH);
  // Wait 2000ms while the module turns on
  delay(2000);
}

// Initializes the LED matrix panel and displays default information
void InitMatrix() {
  // Initialize the matrix
  matrix.begin();
  // Set the text color to white
  matrix.setTextColor(matrix.Color333(7, 7, 7));
  // Set the font size to 1 (8 pixels)
  matrix.setTextSize(1);
  // Move the cursor to the (x=0, y=0) position
  matrix.setCursor(0, 0);
  // Disable text wrap
  matrix.setTextWrap(false);

  // Display a "Wait for data..." message until
  // information is received from the web server
  matrix.println(F("Wait"));
  matrix.setCursor(0, 8);
  matrix.println(F("for"));
  matrix.setCursor(0, 16);
  matrix.println(F("data"));
  matrix.setCursor(0, 24);
  matrix.println(F("..."));
}

// Reads a request received from the web server
void ReadRequest() {
  // Read the incoming command:
  //
  // Read the first character
  current = (char)client.read();
  // Keep reading characters until whitespace or newline is received
  while (current != '\n' && current != ' ') {
    // Store the character
    command[index] = current;
    // Increment the index
    index++;
    // If the command was longer than 3 chars (This shouldn't happen):
    if (index > 3) {
      // Reset the index to prevent out of bounds write
      index = 0;
    }
    // Read another character
    current = (char)client.read();
  }

  // Set the last character to a terminating zero
  // (required for proper storage of char array)
  command[index] = '\0';

  // If the received command is "END":
  if (strcmp(command, "END") == 0) {
    // Close the connection to the web server
    client.stop();
    // Disconnect from the network
    modem.gprsDisconnect();
    return;
  }

  // Reset the index
  index = 0;

  // Read the incoming request:
  //
  // Read the first character
  current = (char)client.read();
  // Keep reading characters until whitespace or newline is received
  while (current != '\n' && current != ' ') {
    // Store the character
    request[index] = current;
    // Increment the index
    index++;
    // If the request was longer than 3 chars (This shouldn't happen):
    if (index > 3) {
      // Reset the index to prevent out of bounds write
      index = 0;
    }
    // Read another character
    current = (char)client.read();
  }

  // Set the last character to a terminating zero
  // (required for proper storage of char array)
  request[index] = '\0';

  // Reset the index
  index = 0;

  // If the incoming command is "SET":
  if (strcmp(command, "SET") == 0) {
    // Handle the SET request
    HandleSet();
  }
  // If the incoming command is "GET":
  else if (strcmp(command, "GET") == 0) {
    // Handle the GET request
    HandleGet();
  }
  // If something went wrong:
  else {
    // Do nothing
    return;
  }
}

// Handles a SET command received from the server
void HandleSet() {
  // Read the value of the command
  ReadValue();

  // If the request is "spd" (Speed limit sign):
  if (strcmp(request, "spd") == 0) {
    // Convert the received value to int for easier calculations later
    int limit = ConvertSpeed();
    // Visualize the speed limit traffic sign with the appropriate value
    VisualizeSpeedLimit(limit);
  }
  // If the request is "wrn" (Warning sign):
  else if (strcmp(request, "wrn") == 0) {
    // Visualize the appropriate warning traffic sign
    VisualizeWarning();
  }
  // If something went wrong:
  else {
    // Do nothing
    return;
  }

  // Update the currently stored device state
  ChangeCurrentState();
  // Send confirmation to the web server
  client.print('k');
}

// Handles a GET command received from the server
void HandleGet() {
  // If the request is "dtl" (Device details):
  if (strcmp(request, "dtl") == 0) {
    // Send the current device details to the web server
    client.print(currentState);
  }
  // If something went wrong:
  else {
    // Do nothing
    return;
  }
}

// Reads the value at the end of a SET request
void ReadValue() {
  // Read the first character
  current = (char)client.read();
  // Keep reading characters until whitespace or newline is received
  while (current != '\n' && current != ' ') {
    // Store the character
    value[index] = current;
    // Increment the index
    index++;
    // If the value was longer than 3 chars (This shouldn't happen):
    if (index > 3) {
      // Reset the index to prevent out of bounds write
      index = 0;
    }
    // Read another character
    current = (char)client.read();
  }
  // Set the last character to a terminating zero
  // (required for proper storage of char array)
  value[index] = '\0';

  // Reset the index
  index = 0;

  // Flush the receive buffer (This also shouldn't happen)
  while (client.available()) {
    client.read();
  }
}

// Converts the request value to integer
int ConvertSpeed() {
  // Returns the received value converted to int
  return atoi(value);
}

// Changes the device state to reflect the currently visualized information
void ChangeCurrentState() {
  int i = 0;  // Index

  // Copy the last received request ot the currentState char array
  for (; i < 3; i++) {
    currentState[i] = request[i];
  }

  // Add a whitespace
  currentState[i] = ' ';
  // Increment the index
  i++;
  // Copy the last received value ot the currentState char array
  for (; i < (strlen(value) + 4); i++) {
    currentState[i] = value[i - 4];
  }

  // Add a terminating zero at the end of the array
  currentState[i] = '\0';
  return;
}

// Displays a speed limit traffic sign with the requested speedLimit
void VisualizeSpeedLimit(int speedLimit) {
  // Draw a large red circle
  matrix.fillScreen(matrix.Color333(0, 0, 0));

  matrix.drawCircle(16, 16, 15, matrix.Color333(7, 0, 0));
  matrix.drawCircle(16, 16, 14, matrix.Color333(7, 0, 0));

  matrix.drawPixel(4, 8, matrix.Color333(7, 0, 0));
  matrix.drawPixel(4, 24, matrix.Color333(7, 0, 0));
  matrix.drawPixel(8, 4, matrix.Color333(7, 0, 0));
  matrix.drawPixel(8, 28, matrix.Color333(7, 0, 0));
  matrix.drawPixel(28, 8, matrix.Color333(7, 0, 0));
  matrix.drawPixel(28, 24, matrix.Color333(7, 0, 0));
  matrix.drawPixel(24, 4, matrix.Color333(7, 0, 0));
  matrix.drawPixel(24, 28, matrix.Color333(7, 0, 0));

  // Draw the speed limit inside the circle in white
  matrix.setTextColor(matrix.Color333(7, 7, 7));

  // Single digit speed limit:
  if (speedLimit < 10) {
    // Set a large font size (24 pixels)
    matrix.setTextSize(3);
    matrix.setCursor(9, 6);
  }
  // Double digit speed limit:
  else if (speedLimit >= 10 && speedLimit < 100) {
    // Set a medium font size (16 pixels)
    matrix.setTextSize(2);
    if (speedLimit < 20) {
      matrix.setCursor(5, 9);
    } else if (speedLimit % 10 == 1) {
      matrix.setCursor(7, 9);
    } else {
      matrix.setCursor(6, 9);
    }
  }
  // Triple digit speed limit:
  else {
    // Set a small font size (24 pixels)
    matrix.setTextSize(1);
    matrix.setCursor(8, 13);
  }

  //
  matrix.println(speedLimit);
}

// Displays the requested warning traffic sign
void VisualizeWarning() {
  if (strcmp(value, "stp") == 0) {
    // Display a stop sign
    VisualizeStopSignWarning();
    return;
  } else if (strcmp(value, "gnr") == 0) {
    // Display a general warning sign (exclamation mark)
    VisualizeGeneralWarning();
    return;
  } else if (strcmp(value, "tfl") == 0) {
    // Display a traffic light warning sign
    VisualizeTrafficLightWarning();
    return;
  } else if (strcmp(value, "nen") == 0) {
    // Display a no entry sign
    VisualizeNoEntryWarning();
    return;
  } else if (strcmp(value, "fon") == 0) {
    // Display a forward only sign
    VisualizeForwardOnlyWarning();
    return;
  } else if (strcmp(value, "lon") == 0) {
    // Display a left only sign
    VisualizeLeftOnlyWarning();
    return;
  } else if (strcmp(value, "ron") == 0) {
    // Display a right only sign
    VisualizeRightOnlyWarning();
    return;
  } else {
    return;
  }
}

// Displays a stop sign
void VisualizeStopSignWarning() {
  matrix.fillScreen(matrix.Color333(0, 0, 0));

  // Red octagon
  matrix.fillRect(9, 0, 14, 2, matrix.Color333(7, 0, 0));
  matrix.fillRect(9, 30, 14, 2, matrix.Color333(7, 0, 0));
  matrix.fillRect(0, 9, 2, 14, matrix.Color333(7, 0, 0));
  matrix.fillRect(30, 9, 2, 14, matrix.Color333(7, 0, 0));

  matrix.drawLine(0, 9, 9, 0, matrix.Color333(7, 0, 0));
  matrix.drawLine(1, 9, 9, 1, matrix.Color333(7, 0, 0));
  matrix.drawLine(22, 0, 31, 9, matrix.Color333(7, 0, 0));
  matrix.drawLine(22, 1, 30, 9, matrix.Color333(7, 0, 0));

  matrix.drawLine(0, 22, 9, 31, matrix.Color333(7, 0, 0));
  matrix.drawLine(1, 22, 9, 30, matrix.Color333(7, 0, 0));
  matrix.drawLine(22, 30, 30, 22, matrix.Color333(7, 0, 0));
  matrix.drawLine(22, 31, 31, 22, matrix.Color333(7, 0, 0));

  // White S
  matrix.fillRect(4, 11, 4, 2, matrix.Color333(7, 7, 7));
  matrix.fillRect(3, 12, 2, 4, matrix.Color333(7, 7, 7));
  matrix.fillRect(4, 15, 4, 2, matrix.Color333(7, 7, 7));
  matrix.fillRect(7, 16, 2, 4, matrix.Color333(7, 7, 7));
  matrix.fillRect(4, 19, 4, 2, matrix.Color333(7, 7, 7));

  // White T
  matrix.fillRect(9, 11, 6, 2, matrix.Color333(7, 7, 7));
  matrix.fillRect(11, 13, 2, 8, matrix.Color333(7, 7, 7));

  // White O
  matrix.fillRect(17, 11, 4, 2, matrix.Color333(7, 7, 7));
  matrix.fillRect(16, 12, 2, 8, matrix.Color333(7, 7, 7));
  matrix.fillRect(17, 19, 4, 2, matrix.Color333(7, 7, 7));
  matrix.fillRect(20, 12, 2, 8, matrix.Color333(7, 7, 7));

  // White P
  matrix.fillRect(23, 11, 5, 2, matrix.Color333(7, 7, 7));
  matrix.fillRect(27, 12, 2, 5, matrix.Color333(7, 7, 7));
  matrix.fillRect(23, 16, 5, 2, matrix.Color333(7, 7, 7));
  matrix.fillRect(23, 11, 2, 10, matrix.Color333(7, 7, 7));
}

// Displays a general warning sign (exclamation mark)
void VisualizeGeneralWarning() {
  matrix.fillScreen(matrix.Color333(0, 0, 0));

  // Red triangle
  matrix.drawTriangle(1, 31, 16, 0, 31, 31, matrix.Color333(7, 0, 0));

  // White exclamation mark
  matrix.drawRect(15, 11, 3, 12, matrix.Color333(7, 7, 7));
  matrix.drawRect(15, 26, 3, 3, matrix.Color333(7, 7, 7));
}

// Displays a traffic light warning sign
void VisualizeTrafficLightWarning() {
  matrix.fillScreen(matrix.Color333(0, 0, 0));

  // Red triangle
  matrix.drawTriangle(1, 31, 16, 0, 31, 31, matrix.Color333(7, 0, 0));

  // Red circle
  matrix.fillCircle(16, 14, 2, matrix.Color333(7, 0, 0));
  // Yellow circle
  matrix.fillCircle(16, 20, 2, matrix.Color333(7, 7, 0));
  // Green circle
  matrix.fillCircle(16, 26, 2, matrix.Color333(0, 7, 0));
}

// Displays a no entry sign
void VisualizeNoEntryWarning() {
  matrix.fillScreen(matrix.Color333(0, 0, 0));

  // Red circle
  matrix.drawCircle(16, 16, 15, matrix.Color333(7, 0, 0));
  matrix.drawCircle(16, 16, 14, matrix.Color333(7, 0, 0));

  matrix.drawPixel(4, 8, matrix.Color333(7, 0, 0));
  matrix.drawPixel(4, 24, matrix.Color333(7, 0, 0));
  matrix.drawPixel(8, 4, matrix.Color333(7, 0, 0));
  matrix.drawPixel(8, 28, matrix.Color333(7, 0, 0));
  matrix.drawPixel(28, 8, matrix.Color333(7, 0, 0));
  matrix.drawPixel(28, 24, matrix.Color333(7, 0, 0));
  matrix.drawPixel(24, 4, matrix.Color333(7, 0, 0));
  matrix.drawPixel(24, 28, matrix.Color333(7, 0, 0));

  // White rectangle
  matrix.fillRect(6, 14, 21, 5, matrix.Color333(7, 7, 7));
}

// Displays a forward only sign
void VisualizeForwardOnlyWarning() {
  matrix.fillScreen(matrix.Color333(0, 0, 0));

  // Blue circle
  matrix.drawCircle(16, 16, 15, matrix.Color333(0, 0, 7));
  matrix.drawCircle(16, 16, 14, matrix.Color333(0, 0, 7));

  matrix.drawPixel(4, 8, matrix.Color333(0, 0, 7));
  matrix.drawPixel(4, 24, matrix.Color333(0, 0, 7));
  matrix.drawPixel(8, 4, matrix.Color333(0, 0, 7));
  matrix.drawPixel(8, 28, matrix.Color333(0, 0, 7));
  matrix.drawPixel(28, 8, matrix.Color333(0, 0, 7));
  matrix.drawPixel(28, 24, matrix.Color333(0, 0, 7));
  matrix.drawPixel(24, 4, matrix.Color333(0, 0, 7));
  matrix.drawPixel(24, 28, matrix.Color333(0, 0, 7));

  // White forward arrow
  matrix.fillRect(15, 14, 3, 13, matrix.Color333(7, 7, 7));

  matrix.fillRect(12, 13, 9, 1, matrix.Color333(7, 7, 7));
  matrix.fillRect(13, 11, 7, 2, matrix.Color333(7, 7, 7));
  matrix.fillRect(14, 9, 5, 2, matrix.Color333(7, 7, 7));
  matrix.fillRect(15, 7, 3, 2, matrix.Color333(7, 7, 7));
  matrix.drawPixel(16, 6, matrix.Color333(7, 7, 7));
}

// Displays a right only sign
void VisualizeRightOnlyWarning() {
  matrix.fillScreen(matrix.Color333(0, 0, 0));

  // Blue circle
  matrix.drawCircle(16, 16, 15, matrix.Color333(0, 0, 7));
  matrix.drawCircle(16, 16, 14, matrix.Color333(0, 0, 7));

  matrix.drawPixel(4, 8, matrix.Color333(0, 0, 7));
  matrix.drawPixel(4, 24, matrix.Color333(0, 0, 7));
  matrix.drawPixel(8, 4, matrix.Color333(0, 0, 7));
  matrix.drawPixel(8, 28, matrix.Color333(0, 0, 7));
  matrix.drawPixel(28, 8, matrix.Color333(0, 0, 7));
  matrix.drawPixel(28, 24, matrix.Color333(0, 0, 7));
  matrix.drawPixel(24, 4, matrix.Color333(0, 0, 7));
  matrix.drawPixel(24, 28, matrix.Color333(0, 0, 7));

  // White right arrow
  matrix.fillRect(12, 13, 3, 12, matrix.Color333(7, 7, 7));
  matrix.fillRect(13, 12, 4, 2, matrix.Color333(7, 7, 7));
  matrix.fillRect(14, 11, 3, 1, matrix.Color333(7, 7, 7));

  matrix.fillRect(17, 8, 1, 9, matrix.Color333(7, 7, 7));
  matrix.fillRect(18, 9, 2, 7, matrix.Color333(7, 7, 7));
  matrix.fillRect(20, 10, 2, 5, matrix.Color333(7, 7, 7));
  matrix.fillRect(22, 11, 2, 3, matrix.Color333(7, 7, 7));
  matrix.drawPixel(24, 12, matrix.Color333(7, 7, 7));
}

// Displays a left only sign
void VisualizeLeftOnlyWarning() {
  matrix.fillScreen(matrix.Color333(0, 0, 0));

  // Blue circle
  matrix.drawCircle(16, 16, 15, matrix.Color333(0, 0, 7));
  matrix.drawCircle(16, 16, 14, matrix.Color333(0, 0, 7));

  matrix.drawPixel(4, 8, matrix.Color333(0, 0, 7));
  matrix.drawPixel(4, 24, matrix.Color333(0, 0, 7));
  matrix.drawPixel(8, 4, matrix.Color333(0, 0, 7));
  matrix.drawPixel(8, 28, matrix.Color333(0, 0, 7));
  matrix.drawPixel(28, 8, matrix.Color333(0, 0, 7));
  matrix.drawPixel(28, 24, matrix.Color333(0, 0, 7));
  matrix.drawPixel(24, 4, matrix.Color333(0, 0, 7));
  matrix.drawPixel(24, 28, matrix.Color333(0, 0, 7));

  // White left arrow
  matrix.fillRect(18, 13, 3, 12, matrix.Color333(7, 7, 7));
  matrix.fillRect(16, 12, 4, 2, matrix.Color333(7, 7, 7));
  matrix.fillRect(16, 11, 3, 1, matrix.Color333(7, 7, 7));

  matrix.fillRect(15, 8, 1, 9, matrix.Color333(7, 7, 7));
  matrix.fillRect(13, 9, 2, 7, matrix.Color333(7, 7, 7));
  matrix.fillRect(11, 10, 2, 5, matrix.Color333(7, 7, 7));
  matrix.fillRect(9, 11, 2, 3, matrix.Color333(7, 7, 7));
  matrix.drawPixel(8, 12, matrix.Color333(7, 7, 7));
}

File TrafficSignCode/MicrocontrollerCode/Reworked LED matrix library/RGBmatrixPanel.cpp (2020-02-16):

/*
RGBmatrixPanel Arduino library for Adafruit 16x32 and 32x32 RGB LED
matrix panels.  Pick one up at:
  http://www.adafruit.com/products/420
  http://www.adafruit.com/products/607

This version uses a few tricks to achieve better performance and/or
lower CPU utilization:

- To control LED brightness, traditional PWM is eschewed in favor of
  Binary Code Modulation, which operates through a succession of periods
  each twice the length of the preceeding one (rather than a direct
  linear count a la PWM).  It's explained well here:

    http://www.batsocks.co.uk/readme/art_bcm_1.htm

  I was initially skeptical, but it works exceedingly well in practice!
  And this uses considerably fewer CPU cycles than software PWM.

- Although many control pins are software-configurable in the user's
  code, a couple things are tied to specific PORT registers.  It's just
  a lot faster this way -- port lookups take time.  Please see the notes
  later regarding wiring on "alternative" Arduino boards.

- A tiny bit of inline assembly language is used in the most speed-
  critical section.  The C++ compiler wasn't making optimal use of the
  instruction set in what seemed like an obvious chunk of code.  Since
  it's only a few short instructions, this loop is also "unrolled" --
  each iteration is stated explicitly, not through a control loop.

Written by Limor Fried/Ladyada & Phil Burgess/PaintYourDragon for
Adafruit Industries.
BSD license, all text above must be included in any redistribution.
*/

#include "RGBmatrixPanel.h"
#include "gamma.h"

#ifdef ARDUINO_ARCH_ESP32
#include <string.h>
#include "driver/timer.h"
#include "freertos/FreeRTOS.h"
#endif

#ifndef _swap_int16_t
#define _swap_int16_t(a, b) \
  {                         \
    int16_t t = a;          \
    a = b;                  \
    b = t;                  \
  }
#endif

// A full PORT register is required for the data lines, though only the
// top 6 output bits are used.  For performance reasons, the port # cannot
// be changed via library calls, only by changing constants in the library.
// For similar reasons, the clock pin is only semi-configurable...it can
// be specified as any pin within a specific PORT register stated below.

#if defined(__AVR_ATmega1280__) || defined(__AVR_ATmega2560__)
// Arduino Mega is now tested and confirmed, with the following caveats:
// Because digital pins 2-7 don't map to a contiguous port register,
// the Mega requires connecting the matrix data lines to different pins.
// Digital pins 24-29 are used for the data interface, and 22 & 23 are
// unavailable for other outputs because the software needs to write to
// the full PORTA register for speed.  Clock may be any pin on PORTB --
// on the Mega, this CAN'T be pins 8 or 9 (these are on PORTH), thus the
// wiring will need to be slightly different than the tutorial's
// explanation on the Uno, etc.  Pins 10-13 are all fair game for the
// clock, as are pins 50-53.
#define DATAPORT PORTA
#define DATADIR DDRA
#define CLKPORT PORTB
#elif defined(__AVR_ATmega32U4__)
// Arduino Leonardo: this is vestigial code an unlikely to ever be
// finished -- DO NOT USE!!!  Unlike the Uno, digital pins 2-7 do NOT
// map to a contiguous port register, dashing our hopes for compatible
// wiring.  Making this work would require significant changes both to
// the bit-shifting code in the library, and how this board is wired to
// the LED matrix.  Bummer.
#define DATAPORT PORTD
#define DATADIR DDRD
#define CLKPORT PORTB
#elif defined(ARDUINO_ARCH_SAMD) || defined(ARDUINO_ARCH_ESP32)
// Support for ATSAMD21-based boards, done with PortType!
#else
// Ports for "standard" boards (Arduino Uno, Duemilanove, etc.)
#define DATAPORT PORTD
#define DATADIR DDRD
#define CLKPORT PORTB
#endif

//#define nPlanes 4
#define nPlanes 2

// The fact that the display driver interrupt stuff is tied to the
// singular Timer1 doesn't really take well to object orientation with
// multiple RGBmatrixPanel instances.  The solution at present is to
// allow instances, but only one is active at any given time, via its
// begin() method.  The implementation is still incomplete in parts;
// the prior active panel really should be gracefully disabled, and a
// stop() method should perhaps be added...assuming multiple instances
// are even an actual need.
static RGBmatrixPanel *activePanel = NULL;

// Code common to both the 16x32 and 32x32 constructors:
void RGBmatrixPanel::init(uint8_t rows, uint8_t a, uint8_t b, uint8_t c,
                          uint8_t clk, uint8_t lat, uint8_t oe, boolean dbuf,
                          uint8_t width
#if defined(ARDUINO_ARCH_SAMD) || defined(ARDUINO_ARCH_ESP32)
                          ,
                          uint8_t *pinlist
#endif
) {
#if defined(ARDUINO_ARCH_SAMD) || defined(ARDUINO_ARCH_ESP32)
  // R1, G1, B1, R2, G2, B2 pins
  static const uint8_t defaultrgbpins[] = {2, 3, 4, 5, 6, 7};
  memcpy(rgbpins, pinlist ? pinlist : defaultrgbpins, sizeof rgbpins);
#if defined(ARDUINO_ARCH_SAMD)
  // All six RGB pins MUST be on the same PORT # as CLK
  int clkportnum = g_APinDescription[clk].ulPort;
  for (uint8_t i = 0; i < 6; i++) {
    if (g_APinDescription[rgbpins[i]].ulPort != clkportnum) return;
  }
#endif
#endif

  nRows = rows;  // Number of multiplexed rows; actual height is 2X this

  // Allocate and initialize matrix buffer:
  // int buffsize  = width * nRows * 3, // x3 = 3 bytes holds 4 planes "packed"
  int buffsize = width * nRows,
      allocsize = (dbuf == true) ? (buffsize * 2) : buffsize;
  // if(NULL == (matrixbuff[0] = (uint8_t *)malloc(allocsize))) return;
  matrixbuff[0] = buff;
  memset(matrixbuff[0], 0, allocsize);
  // If not double-buffered, both buffers then point to the same address:
  matrixbuff[1] = (dbuf == true) ? &matrixbuff[0][buffsize] : matrixbuff[0];

  // Save pin numbers for use by begin() method later.
  _a = a;
  _b = b;
  _c = c;
  _clk = clk;
  _lat = lat;
  _oe = oe;

  // Look up port registers and pin masks ahead of time,
  // avoids many slow digitalWrite() calls later.
  clkmask = digitalPinToBitMask(clk);
  latport = portOutputRegister(digitalPinToPort(lat));
  latmask = digitalPinToBitMask(lat);
  oeport = portOutputRegister(digitalPinToPort(oe));
  oemask = digitalPinToBitMask(oe);
  addraport = portOutputRegister(digitalPinToPort(a));
  addramask = digitalPinToBitMask(a);
  addrbport = portOutputRegister(digitalPinToPort(b));
  addrbmask = digitalPinToBitMask(b);
  addrcport = portOutputRegister(digitalPinToPort(c));
  addrcmask = digitalPinToBitMask(c);
  plane = nPlanes - 1;
  row = nRows - 1;
  swapflag = false;
  backindex = 0;  // Array index of back buffer
}
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

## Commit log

2019-12-18 Schematic with 12V->4V buck converter
    [TrafficSign.kicad_pcb, TrafficSign.sch]
2020-01-09 Full schematic with links to elements
    [TrafficSign.sch]
2020-01-14 Test server/client with python sockets
2020-01-18 Server thread listening to client requests
2020-01-19 Added footprints to all elements
    [TrafficSign.sch, TrafficSignFull.sch]
2020-01-19 PCB elements import
    [TrafficSignFull.kicad_pcb, TrafficSignFull.sch, TrafficSignPCB.kicad_pcb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]
2020-01-20 Placed elements on PCB (Not final)
    [TrafficSignPCB.kicad_pcb, TrafficSignPCB.sch]
2020-01-20 Element placement v2
    [TrafficSignPCB.kicad_pcb, TrafficSignPCB.sch]
2020-01-20 Router IDC connector
    [TrafficSignPCB.kicad_pcb]
2020-01-20 Router everything
    [TrafficSignPCB.kicad_pcb]
2020-01-20 Added Elsys logo to PCB
    [TrafficSignPCB.kicad_pcb, TrafficSignPCB.sch]
2020-01-20 Added dimensions to PCB
    [TrafficSignPCB.kicad_pcb]
2020-01-20 Added schematic PDFs and PCB picture
2020-01-20 Added more PCB images
2020-01-20 Admin app requesting device list
2020-01-20 Adding to device list
2020-01-21 Added missing capacitors, changed converter output capacitors to Low ESR
    [TrafficSignPCB.sch]
2020-01-21 Changed element placement and rerouted board
    [TrafficSignPCB.kicad_pcb]
2020-01-21 Added PCB and schematic images
    [TrafficSignPCB.kicad_pcb, TrafficSignPCB.sch]
2020-01-22 Changed buck converter layout
    [TrafficSignPCB.kicad_pcb, TrafficSignPCB.sch]
2020-01-23 Moved buck convertors(again)
2020-01-23 Forgot to save...
    [TrafficSignPCB.kicad_pcb, TrafficSignPCB.sch]
2020-01-23 Moving elements
    [TrafficSignPCB.kicad_pcb, TrafficSignPCB.sch]
2020-01-23 PCB v3
    [TrafficSignPCB.kicad_pcb]
2020-01-23 Added images
    [TrafficSignPCB.kicad_pcb]
2020-01-25 Working admin app multithreading
    [TrafficSignPCB-B_Cu.gbr, TrafficSignPCB-B_Mask.gbr, TrafficSignPCB-Edge_Cuts.gbr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]
2020-01-25 Device list refresh
2020-01-26 Fixed GET and SET request format on admin app and server
    [MicrocontrollerCode.ino]
2020-01-27 Sending speed limit to device
2020-01-27 Black magic arduino library
2020-01-30 Reworked Adafruit's library to display less colors and thus use less RAM. Now working with TinyGSM
    [MicrocontrollerCode.ino, RGBmatrixPanel.cpp]
2020-01-30 Fixing set speed limit command
    [MicrocontrollerCode.ino]
2020-01-31 Fixed speed limit number visualization
    [MicrocontrollerCode.ino]
2020-02-01 Saving known devices to .yaml file on Admin app
2020-02-01 Added set device alias option to admin app
2020-02-01 Saving current sign state in uC code
2020-02-02 Details button functionality
2020-02-04 Fixed login refusal on too many attempts
    [MicrocontrollerCode.ino]
2020-02-06 Fixed IPs (and a small bug) and deployed to AWS
    [MicrocontrollerCode.ino]
2020-02-09 Updated full schematic
    [TrafficSignFull.sch]
2020-02-10 Seperated schematic into blocks
    [TrafficSignFull.sch]
2020-02-12 Reordered some stuff and fixed a resistor value
    [TrafficSignFull.sch]
2020-02-13 Removed connector from full schematic power block
    [TrafficSignFull.sch]
2020-02-14 Added an aditional voltage divider
    [TrafficSignFull.sch]
2020-02-15 Fixed SSL socket creation
2020-02-15 Fixed web server threads
2020-02-15 Changed admin thread handling
2020-02-16 Forgot a bracket
2020-02-18 Updated the PCB schematic and layout
    [TrafficSignPCB.kicad_pcb, TrafficSignPCB.sch]
2020-02-18 Made small adjustments to PCB design
    [TrafficSignPCB.kicad_pcb, TrafficSignPCB.sch]
